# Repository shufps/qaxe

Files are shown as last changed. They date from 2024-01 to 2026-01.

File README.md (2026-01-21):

# NerdQ Hardware Repository

This repository contains multiple generations of small-scale Bitcoin miner hardware designs.

## NerdQAxe++



Current high-performance design based on 4× BM1370 ASICs.



- ~4.8 TH/s at ~76 W (~15.8 J/TH)
- Previous stable version (that was used for most NQ++): [rev5.1](https://github.com/shufps/qaxe/releases/tag/rev5.1)
- Latest:  [rev5.1.2](https://github.com/shufps/qaxe/releases/tag/rev5.1.2)*

*: contains some [improvements](https://github.com/shufps/qaxe/pull/31) but is untested yet.

## NerdQAxe+



Design based on 4x BM1368 ASICs.

- ~2.5TH/s at ~55 W (~22 J/TH)
- Latest revision 5.0

## Firmware for NQ+ and NQ++

The latest version can be found here:

https://github.com/shufps/ESP-Miner-NerdQAxePlus

## Legacy Designs

The following designs are **end of life** and no longer supported:

- QAxe+
- QAxe

They are provided for reference, documentation, and historical reasons only.

**No support, fixes, or updates will be provided for legacy designs.**

See `legacy/README.md` for full documentation of deprecated hardware.

---

## Compatible Replacement Parts

### For NerdQAxe++
- 25 MHz Oscillator
  Original: IQD LFSPXO076024
  Replacement: Taitien OXLTDLJANF-25.000000

### For NerdQAxe++ and NerdQAxe+
- 0.8 V LDO
  Original: Microchip MCP1824T-0802E-OT
  Replacement: TI TPS78408QDBVRQ1

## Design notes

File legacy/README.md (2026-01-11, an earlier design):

# Legacy Hardware Designs

⚠️ **Status: End of Support**

This directory contains deprecated hardware designs that are no longer maintained.

- No bug fixes
- No hardware revisions
- No firmware updates
- No user support

The designs are provided **as-is** for reference and historical documentation.

---

## QAxe+



Quad-BM1368 miner.

- ~2.4 TH/s at ~55 W (230 V measured)
- Final revisions: rev4 / rev4.1
- Known quirks with ASIC reset behavior

---

## QAxe



Quad-BM1366 miner.

- ~1.7–1.8 TH/s depending on revision
- Multiple early hardware revisions (rev1–rev3.2)

Notes:
- Boards with BOOT button require STM32L072CB
- USB DFU bootloader recommended for flashing

---

Firmware & Tooling
=====================

Legacy firmware, build instructions, and tooling are preserved for completeness.
They may require outdated dependencies and are not guaranteed to work on modern systems.

## Compilation (Bootloader or CMSIS-DAP) (QAxe, QAxe+)

### Dockered compilation and flashing
There is a wonderfull Docker based single-script compilation and flash tool for the QAxe Firmware:

https://github.com/AnimaI/QAxe-Docker-Bootloader

### Manual compilation and installation

```bash
# install curl
sudo apt install curl

# install rust
curl --proto '=https' --tlsv1.2 https://sh.rustup.rs -sSf | sh

# add to ~/.bash.rc (afterwards, opening a new terminal is needed)
echo 'source "$HOME/.cargo/env"' >> ~/.bashrc

# clone repository
git clone https://github.com/shufps/qaxe

# clone submodules
cd qaxe
git submodule init
git submodule update

# add rust target for STM32L0 variants
rustup target add thumbv6m-none-eabi

# or add rust target for STM32L1 variants
#rustup target add thumbv7m-none-eabi

# build firmware for L072
cd firmware/fw-L072CB
./build.sh
```

### Installation via USB Bootloader on board with `BOOT` button (QAxe, QAxe+)
The STM32L072CB variant has an integrated DFU Bootloader that starts when pressing the `BOOT` button during reset.

Afterwards the firmware can be flashed via `dfu-utils`:

```bash
# install cargo-binutils and llvm tools
cargo install cargo-binutils
rustup component add llvm-tools-preview

# create the firmware.bin
DEFMT_LOG=info cargo objcopy --release --bin qaxe -- -O binary qaxe.bin

# install dfu-utils
sudo apt-get install dfu-util

now start the stm32 in DFU mode by pressing `boot` (only works with the STM32L072CB variant)

# after booting, list the devices
dfu-util --list

# flash the binary
dfu-util -a 0 -s 0x08000000:leave -D qaxe.bin
```

Mining Client (QAxe, QAxe+)
=============



Stratum Mining Client:<br>
https://github.com/shufps/piaxe-miner

---

## Disclaimer

These designs are **not recommended for new builds**.

If you are looking for a supported and actively developed project, refer to the main repository README.

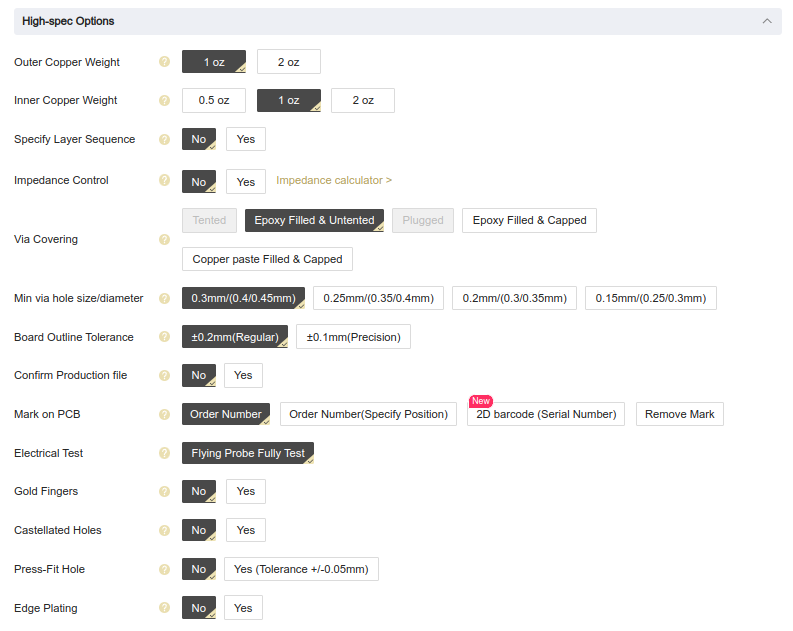
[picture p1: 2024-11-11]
nerdqaxe++/gerbers/jlc-settings2.png

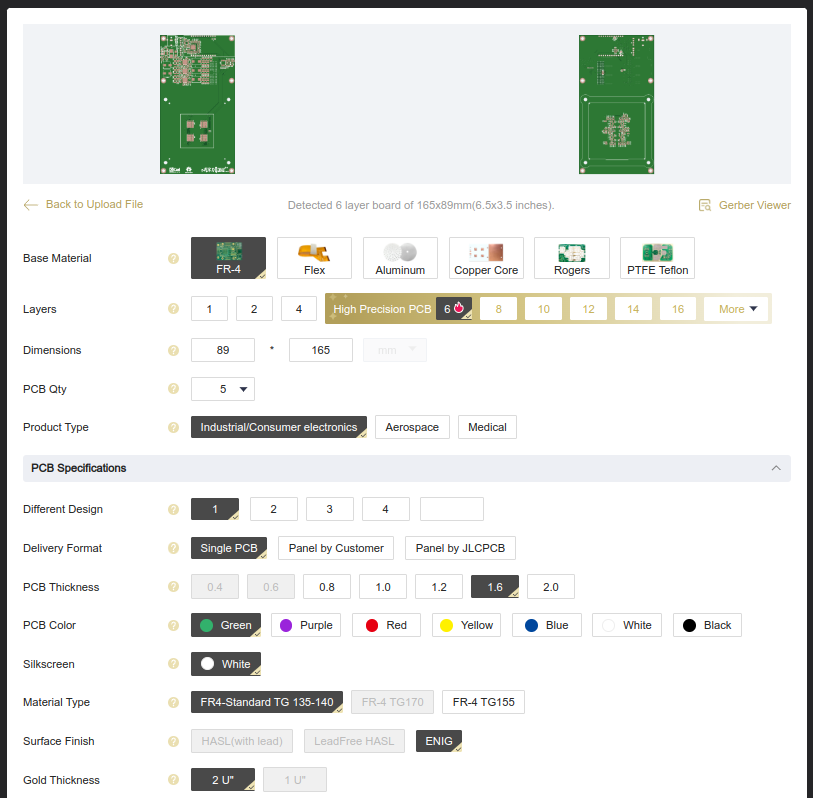
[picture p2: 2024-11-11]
nerdqaxe++/gerbers/jlc-settings1.png

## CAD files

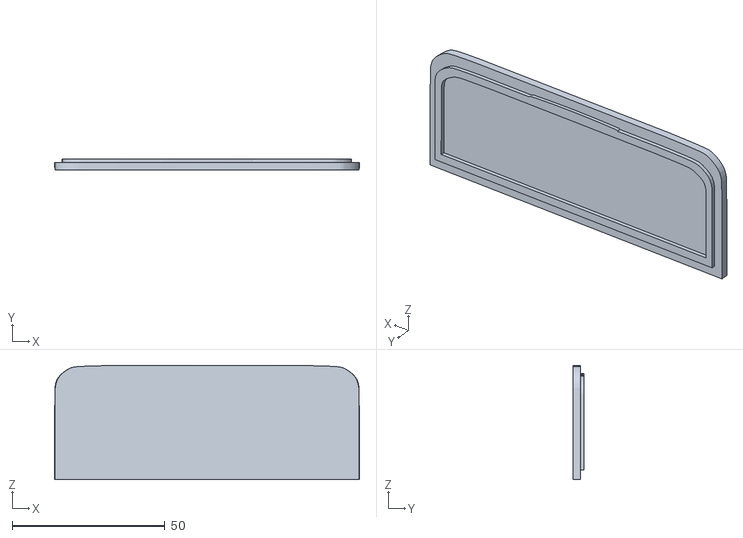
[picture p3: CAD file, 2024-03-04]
case/back.stl
99.7 x 3.54 x 37.3

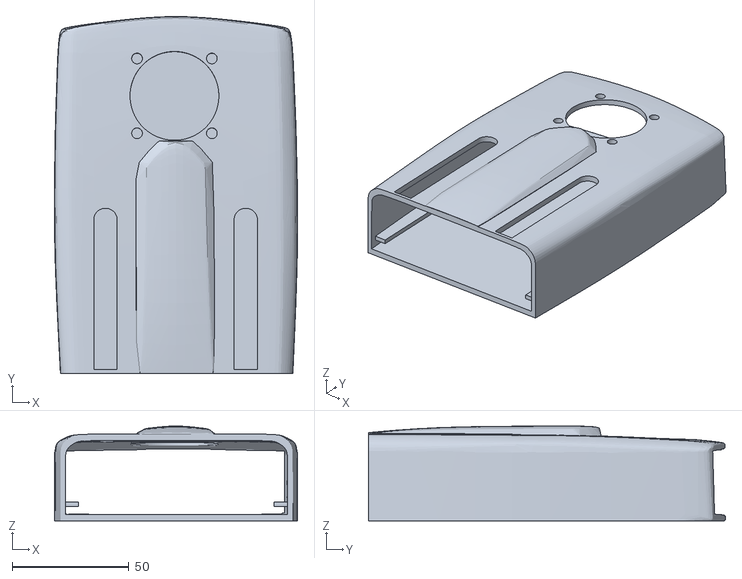
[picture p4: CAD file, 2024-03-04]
case/case.stl
104.1 x 152.7 x 40.6

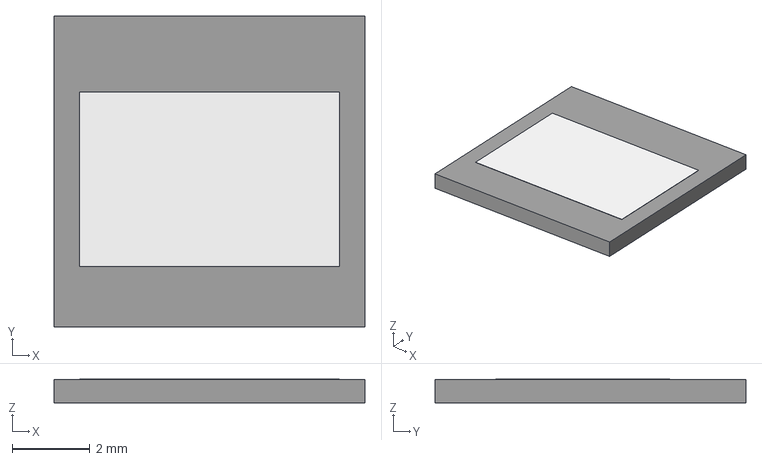
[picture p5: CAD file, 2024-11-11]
nerdqaxe++/nerdqaxe++/3d/bm1370.step
8.00 x 8.00 x 0.61 mm

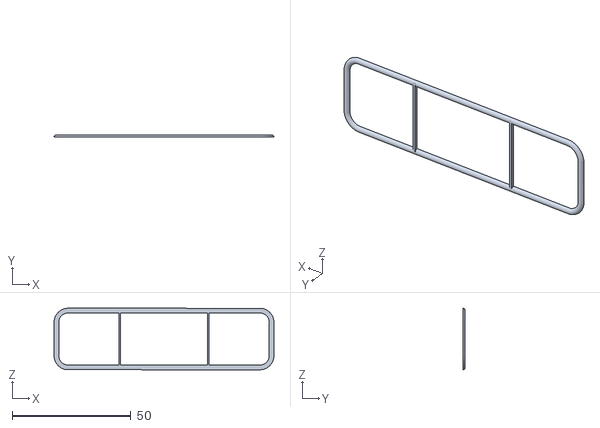
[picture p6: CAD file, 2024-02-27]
case/grill-part2.stl
92.7 x 1.00 x 26.0

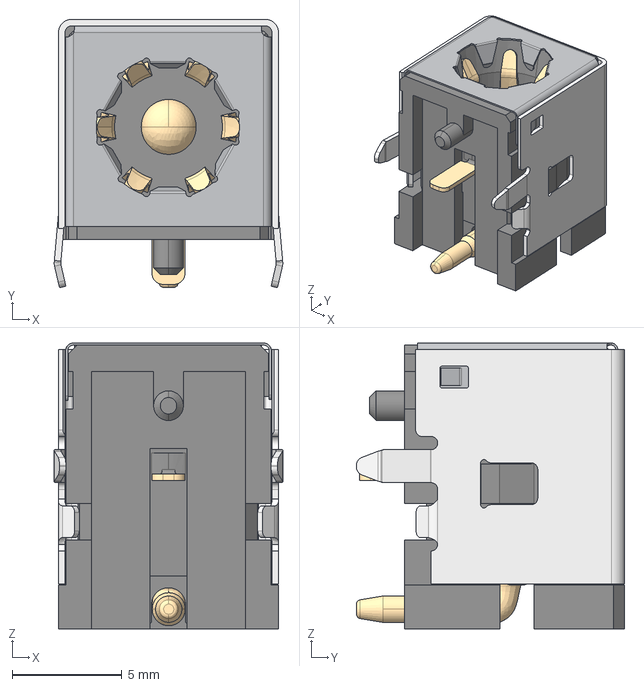
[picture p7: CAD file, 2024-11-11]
nerdqaxe++/nerdqaxe++/3d/DCJ250-20-B-XX-X_REVA1.step
10.4 x 12.2 x 13.0 mm

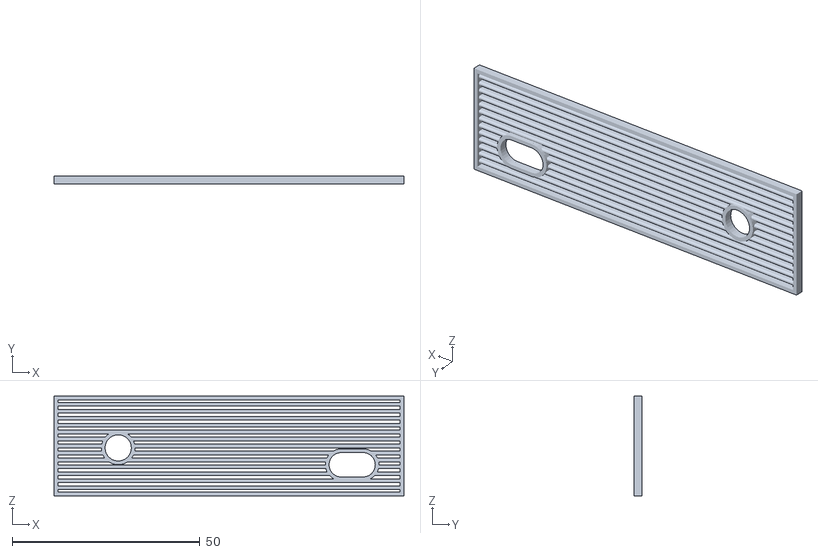
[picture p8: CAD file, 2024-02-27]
case/grill-part1.stl
93.2 x 2.00 x 26.5

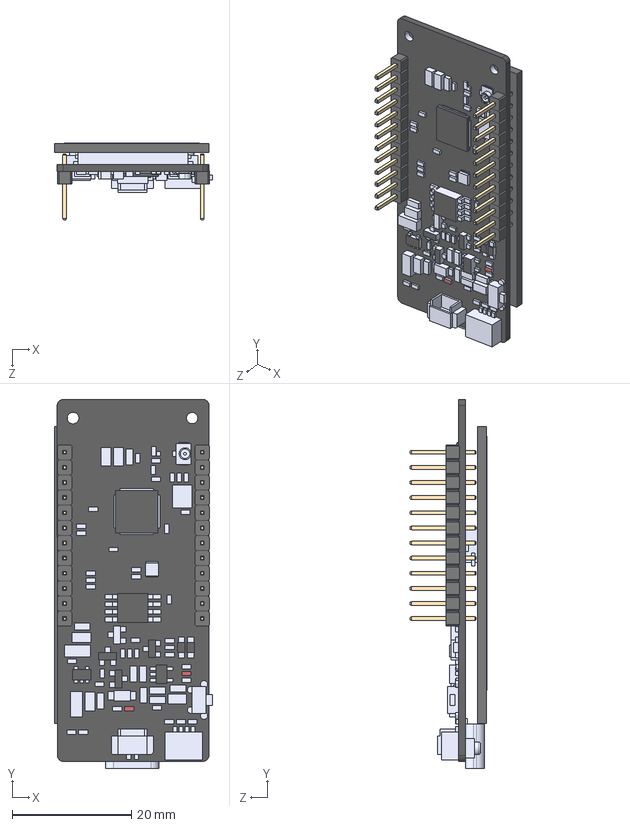
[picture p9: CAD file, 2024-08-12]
nerdqaxe++/nerdqaxe++/3d/T-Display-S3.STEP
26.5 x 62.0 x 12.9 mm
MainBoard_3D
Ecran
1_Male_Pin_2.54_mm x 24

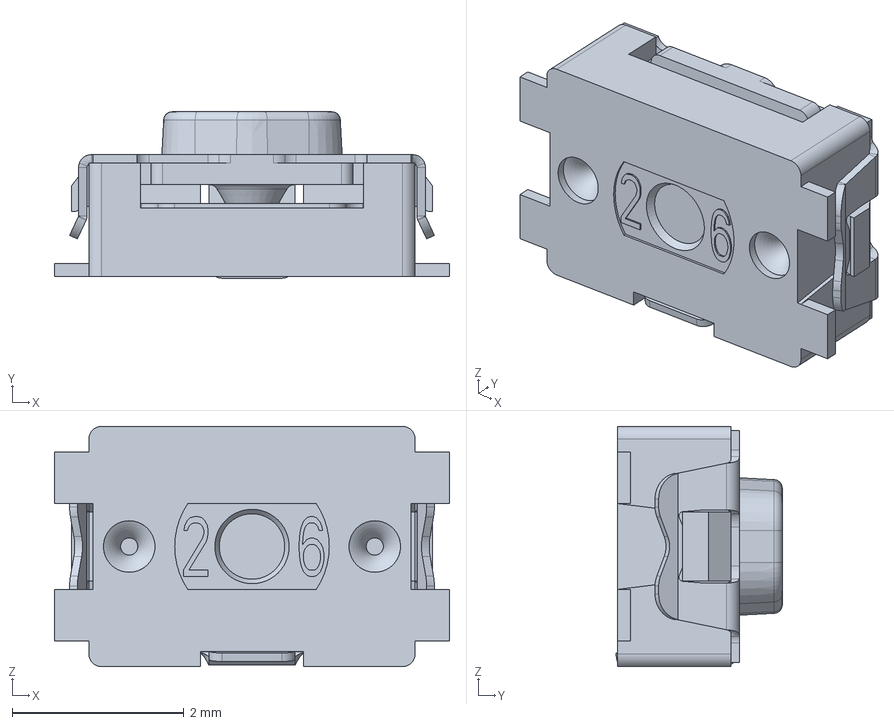
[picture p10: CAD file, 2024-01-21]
nerdqaxe++/nerdqaxe++/3d/KMR231GLFS.stp
4.60 x 1.94 x 2.80 mm

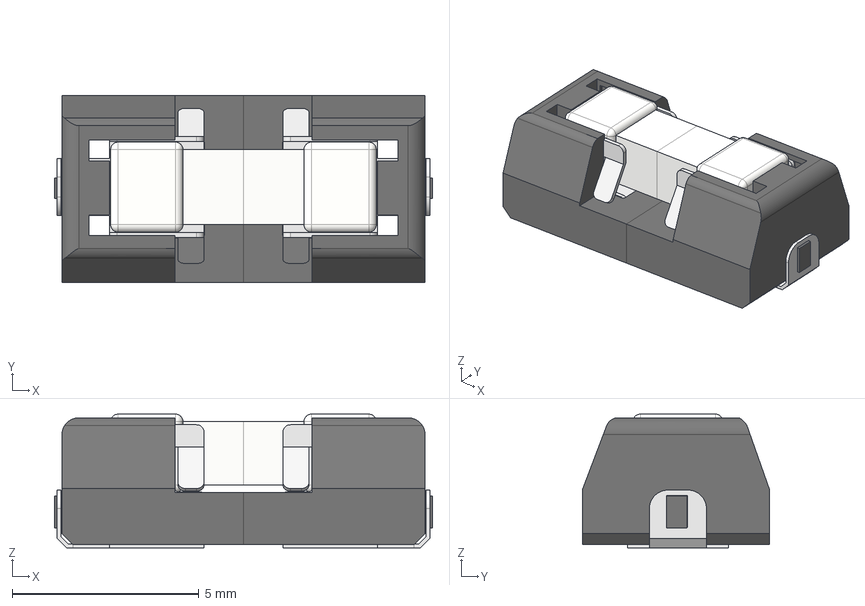
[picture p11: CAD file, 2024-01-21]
nerdqaxe++/nerdqaxe++/3d/Littelfuse 0154.500DRT without value_black v2.step
10.1 x 5.00 x 3.59 mm
Komponente1
Komponente2
Komponente3
Komponente4

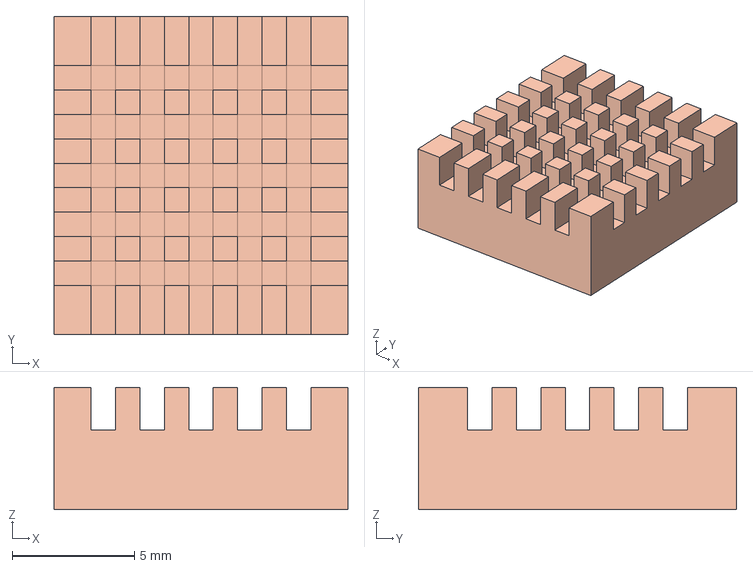
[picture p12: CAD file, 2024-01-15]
nerdqaxe++/nerdqaxe++/3d/heatsink-13x12x5.step
12.0 x 13.0 x 5.00 mm

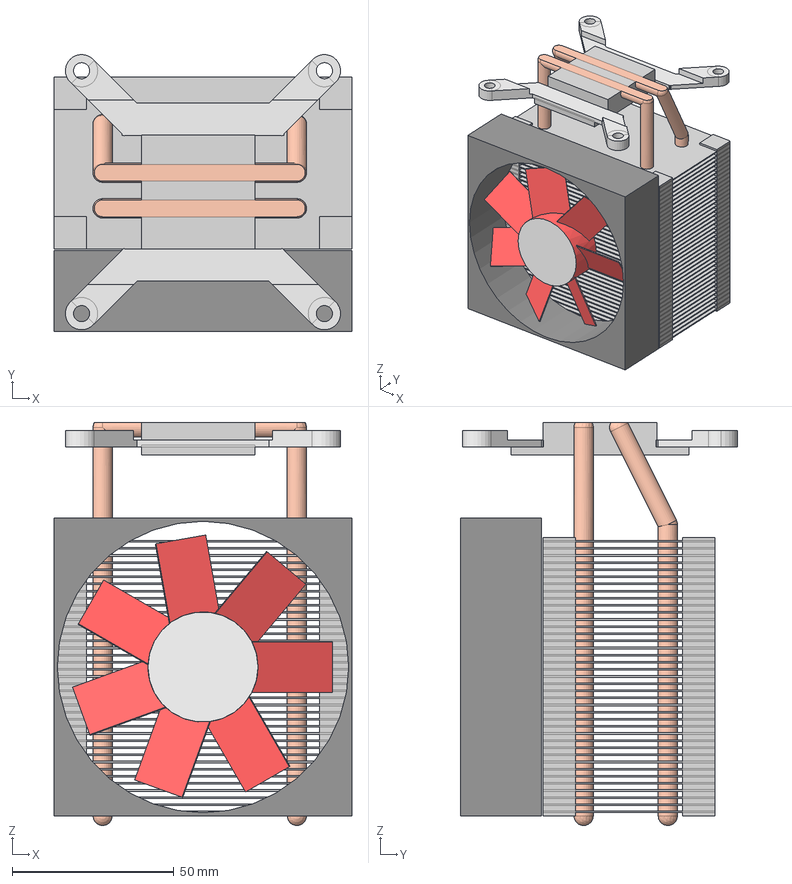
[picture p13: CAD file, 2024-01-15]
nerdqaxe++/nerdqaxe++/3d/lga115x.step
92.0 x 85.5 x 124.5 mm

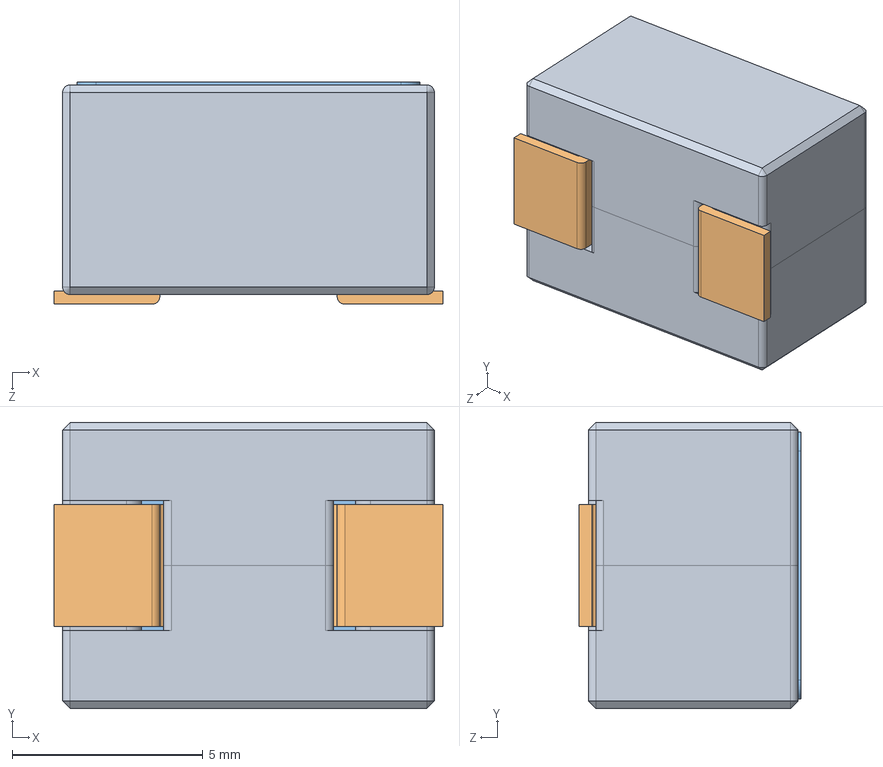
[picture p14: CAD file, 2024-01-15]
nerdqaxe++/nerdqaxe++/3d/FP1006V2-R.STEP
10.2 x 7.50 x 5.83 mm
11150900A x 2
53134900A
Label for FP1006V2-R

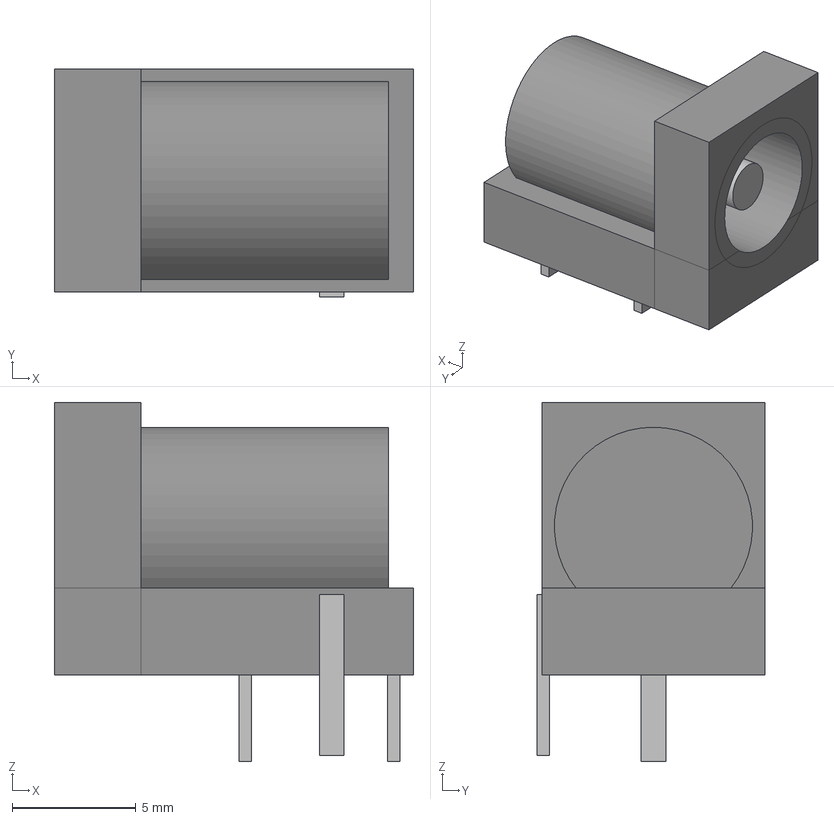
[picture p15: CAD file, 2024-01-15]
nerdqaxe++/nerdqaxe++/3d/barrel-jack.step
14.5 x 9.20 x 14.5 mm

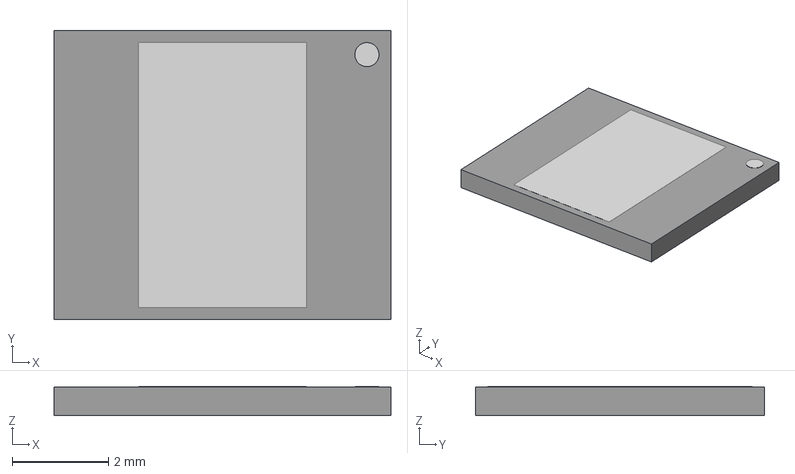
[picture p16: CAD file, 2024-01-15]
nerdqaxe++/nerdqaxe++/3d/bm1366.step
7.00 x 6.00 x 0.61 mm

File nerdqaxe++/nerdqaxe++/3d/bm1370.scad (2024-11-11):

$fn=50;

color("#505050") translate([0,0,0.3]) cube([8,8,0.6], center=true);
color("lightgray") translate([0,-0.2,0.51]) cube([6.7, 4.5, 0.2], center=true);

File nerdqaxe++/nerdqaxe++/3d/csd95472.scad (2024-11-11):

$fn=50;

color("#505050") translate([0,0,0.5]) cube([5,6,1], center=true);

color("lightgray") union() {
    for (i=[-5:5]) {
        translate([5/2-0.24, i*0.5, 0.095]) cube([0.5, 0.25, 0.2], center=true);
        translate([-5/2+0.24, i*0.5, 0.095]) cube([0.5, 0.25, 0.2], center=true);
    }
    
    translate([1+0.25/2, 3-0.10, 0.1]) cube([0.25, 0.3, 0.25], center=true);
    translate([-(1+0.25/2), 3-0.10, 0.1]) cube([0.25, 0.3, 0.25], center=true);

    translate([1+0.25/2, -(3-0.10), 0.1]) cube([0.25, 0.3, 0.25], center=true);
    translate([-(1+0.25/2), -(3-0.10), 0.1]) cube([0.25, 0.3, 0.25], center=true);

    translate([0, 0, 0.1]) cube([3, 5.5, 0.25], center=true);    
}

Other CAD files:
nerdqaxe++/nerdqaxe++/3d/csg95472.step

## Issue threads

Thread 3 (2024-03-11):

Add 5V power to USB port (for Pi Zero)

AxisRay, 2024-03-11:
Can you add 5V power to USB port?
So I can connect the Pi Zero with just one cable.
And it does not require an additional power adapter.
The Pi Zero consumes less than 600mA of power.
Perhaps that 5V buck circuit can handle the load.

shufps, 2024-03-29:
Interesting idea :thinking:  Mmhmmmm, it could work :thinking: would be cool if the existing usb-c could be used for powering the Pi but I don't think it works this way :see_no_evil:

AxisRay, 2024-04-19:
I think it will work.
I have used a OTG cable with power supply.
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

bohnelang, 2024-06-16:
It would be nice too if you could add 2 pin holes with 12V and GND next to the power socket. In the front part of the board you have already 4 holes for mounting. With some spacer one could design a carrier board that can take a NanoPi NEO v1.4 (Allwinner H3) or a Pi Zero or a ZeroPi (this is not a Pi Zero). Like a sandwich. To supply any future carrier board with power this small modification would be nice. The carrier board itself can use a down stepper (12V to 5V) to supply the Pi or other micro controllers .

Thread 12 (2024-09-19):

Update digikey.csv / ibom.html

marplukiwi, 2024-09-19:
I compared all the articles for the NerdQAxe+ from the digikey.csv with the ibom.html and I noticed the following discrepancies that need to be clarified.

Capacitors

C15, C17, C21, C22, C24, C39 are supposed to have 100µF 6.3V but in the digikey.csv the article 399-C1210C107M8PAC7800CT-ND has 100µF 10V. Can this also be used?

C112, C117 are supposed to have 3.3n/25V. The article 490-8291-1-ND from the digikey.csv has 3.3n/100V

The capacitor C100 with 10µ/25V is not included in the .csv. Was this forgotten or is the capacitor not needed according to the latest version?

Then I noticed that in the PCB editor the labeling of the capacitors C90 and C21 is swapped compared to the Ibom. Is that a mistake?

Do the solder jumpers JP1, JP, and JP3 have to be installed? In the circuit diagram they are drawn as open.

I just want the documentation to be clean so that it is easier for others.

MyOwn2C, 2025-03-03:
One more change for NerdQAxe+ is to replace the 5A fuse with 8A fuse:

8A Fuse:
https://www.digikey.ca/short/2pwrfv2t

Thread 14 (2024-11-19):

NerdQAxe++ build guide

invisibleecho, 2024-11-19:
Hello,

I was about to order an avalon nano 3, but 4TH/s @ 140Watts is not too efficient. I saw bitaxe gamma at 1.2TH/s @ 15Watts which is impressive but expensive for like 229€ each unit.

Im aiming to get an efficient home miner which gets good speed like 8TH/s under 200 Watts and your project looks insane!

Are there any tutorials on how to build this yourself? Do you have a list of parts and where to get the correct parts or something like this?

I need one of those! :)

Thanks for your awesome work!

Best regards

shufps, 2024-12-06:
Hi,

thank you a lot for your interest in this project :hugs:

> Are there any tutorials on how to build this yourself? Do you have a list of parts and where to get the correct parts or something like this?

Hmm, to be honest, the complexity of such miner is on "pro-level" and even people with skills obtained over decades struggle with it.

So I guess there is no tutorial how to do it - if you have the skills required the information from this repository are enough (the project has been completed by several people already - with maybe a little help in the OSMU Discord channel). :speak_no_evil:

Yes, there is a list of parts called BOM (bill of material). This are csv lists that can be imported into Digikey for ordering.

Best regards

Closed 2024-12-06.

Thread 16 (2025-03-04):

Change power connector as an improvement

Comphil, 2025-03-04:
I was wondering whether it is possible to replace the power connector on the nerdqaxe++ (BOM: J1). The connector is difficult to order and I don't find any alternatives. It's possible to change to an XT30U-M in vertical position? I think you have no problems with the amperage [A] and the voltage [V]. I'm aware that it requieres a special cable, wich I can make myself (together with a meanwell power supply).
Can someone adapt the pcb-board for me (unfortunately I have only a little experience with kicad).
Maybe this suggestion should be seen as an improvement and incorporated into the project?
Thank you and stay healthly.

shufps, 2025-03-05:
👋 Hmm I had a look at it and I haven't found any nice way to use optionally a XT30 connector because I want to keep the barrel jack because most people use it.

Maybe you can solder cables directly to the board instead of using the barrel jack connector?

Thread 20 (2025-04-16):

Bug Report: Unexpected Fan Stoppage During Power-On with Single 1370 Chip Testing

myeyesareopen, 2025-04-16:
Description
When testing the 1370 chip using NerdQAxe, I consistently observe unexpected fan behavior during system startup:

Observed Symptoms :

Case 1:
Fan spins up after power-on
Then decelerates/stops unexpectedly
Subsequently accelerates again and boots normally
Case 2:
Fan spins for 3-5 seconds after power-on
Completely stops with boot failure
Additional Context :

Issue persists across multiple firmware versions from 1.0.25 to 1.0.28.1

Request :
Could you help confirm:
Is this a known/common issue with the 1370 chip?
Any recommended configuration adjustments?
Required debug data for further analysis?

shufps, 2025-06-18:
Mmhmm, can be that this is the "fan polarity auto detection" feature that tries two different fan settings to find out which PWM polarity is the correct one.

It hmm stops with boot failure? How does this look like?

Have you photos or a log you could post?

PS: The auto detect feature can be turned off in the "Danger Zone".

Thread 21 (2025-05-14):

Feature Request: Support ASIC Temperature Readout for BM1370 (Display, Logs, API)

IxTechCrypto, 2025-05-14:
**Request**
Requesting support to read the ASIC temperature directly from the BM1370 chip—similar to how Bitaxe and NerdAxe Gamma implementations handle temperature monitoring (Skot and Bitmaker may have more insight on how to implement this). This would enhance observability and thermal safety, especially for users running overclocked configurations.

**Expected Behavior**
Temperature is read from internal BM1370 registers

**Output is:**
- Logged via UART/serial
- Avg chip temp displayed on Lillygo screen
- Exposed through any available web API or telemetry endpoints

IxTechCrypto, 2025-05-21:
moving to the esp miner repo

Closed 2025-05-21.

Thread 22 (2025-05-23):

TPS_TSEN network is a single-point network

manan1199, 2025-05-23:
Should pin 40 of U3 be connected to pin 11 of U4, U9, and U10? Their network names seem to be the same, but they are all single-point networks. The specification sheet indicates that connecting them would be more beneficial for detecting the temperature of the power system.

Closed 2025-06-01.

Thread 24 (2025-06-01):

Wrong Pinout for II2C and UART

FireCloudHD, 2025-06-01:
The pinout for the II2C and UART interface (Signal names: TXD, RXD, SDA, SCL) do not match the pinout of the T-Display-S3 from this repository: https://github.com/Xinyuan-LilyGO/T-Display-S3

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

Is this an error in the schematic, or is the pinout intended for a different T-Display-S3?

Happy to hear any suggestions, thank you.

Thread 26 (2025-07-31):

Feature request: Log PCB reference next to ASIC number

janix12, 2025-07-31:
Hi,

I'd like to request a small improvement in the log output.
Currently, ASICs are identified in the logs as:

AsicNr 0
AsicNr 1
AsicNr 2
AsicNr 3
It would be very helpful if the corresponding PCB / KiCad reference (e.g., U20, U19, etc.) could also be printed alongside, like this:

AsicNr 0 - U20
AsicNr 1 - U19
...
This would make it much easier to locate and repair faulty ASICs during debugging or hardware servicing.
Thanks in advance for considering this!

Best regards,
János

Closed 2025-07-31.

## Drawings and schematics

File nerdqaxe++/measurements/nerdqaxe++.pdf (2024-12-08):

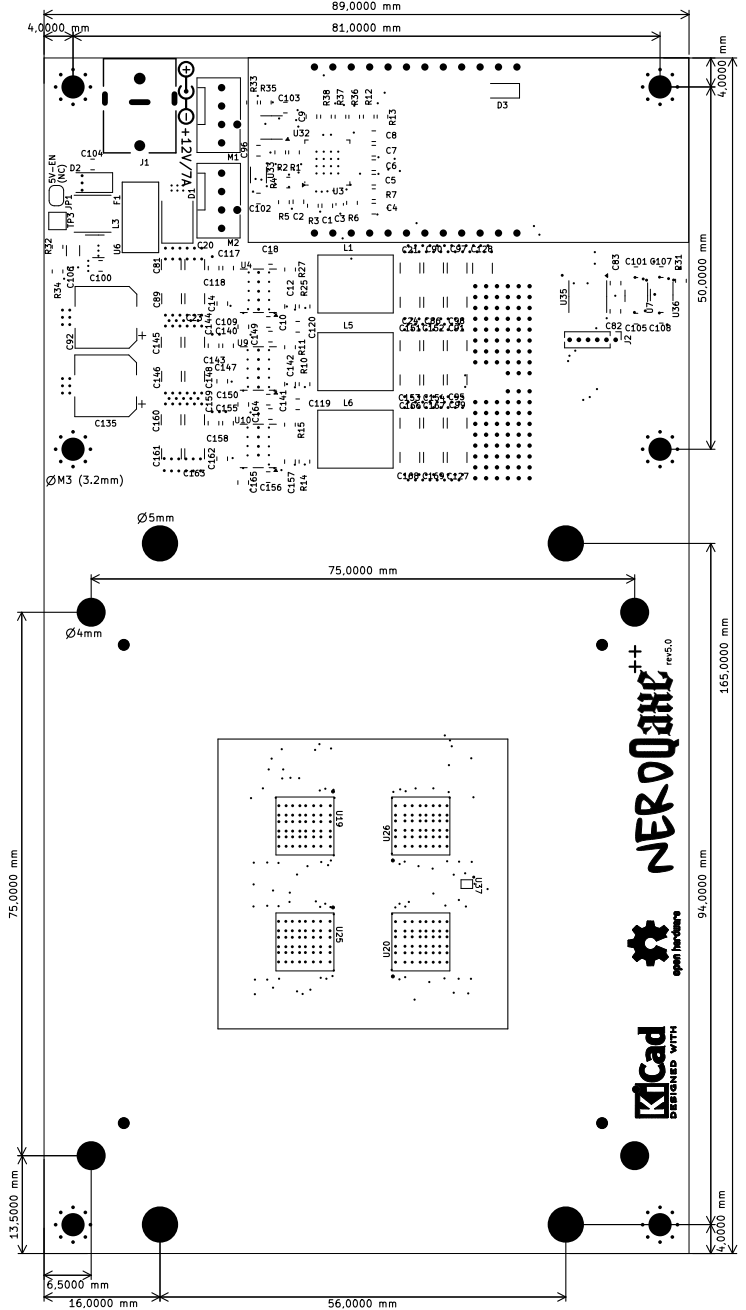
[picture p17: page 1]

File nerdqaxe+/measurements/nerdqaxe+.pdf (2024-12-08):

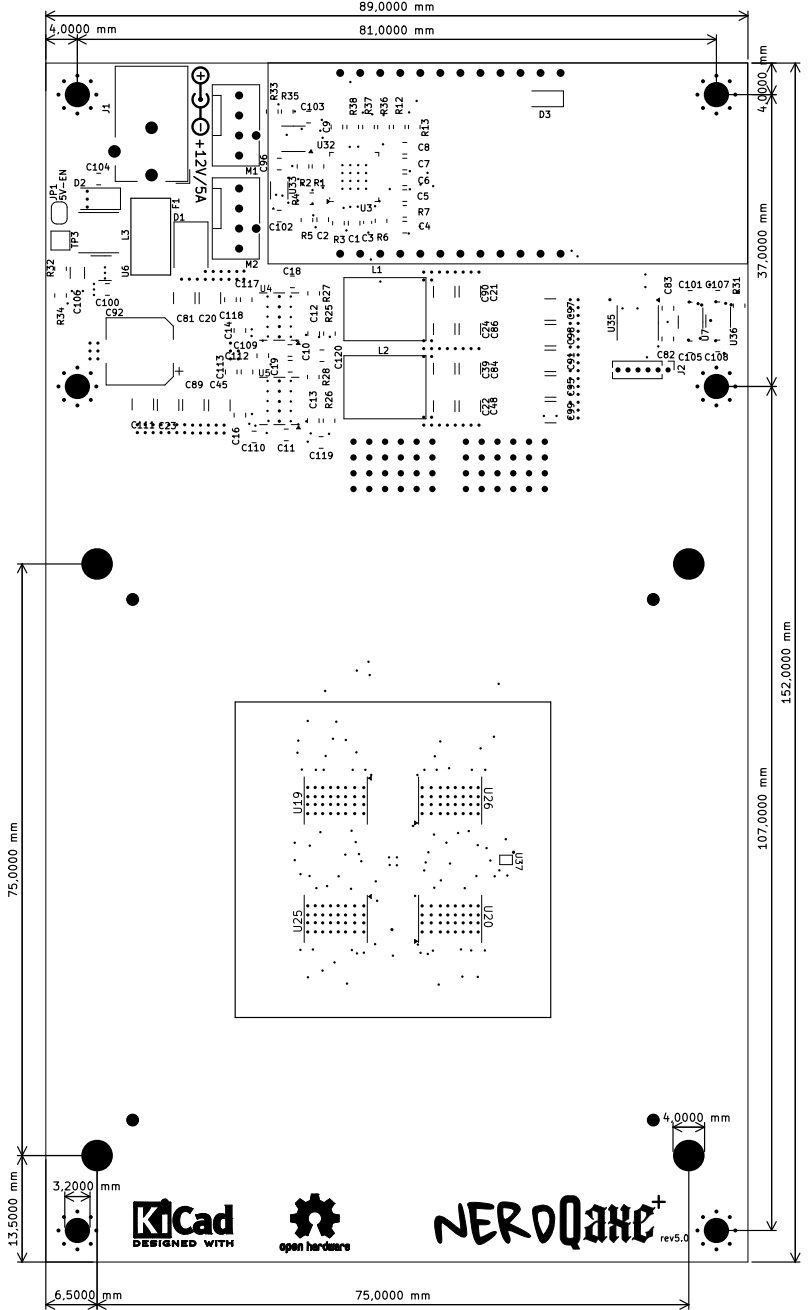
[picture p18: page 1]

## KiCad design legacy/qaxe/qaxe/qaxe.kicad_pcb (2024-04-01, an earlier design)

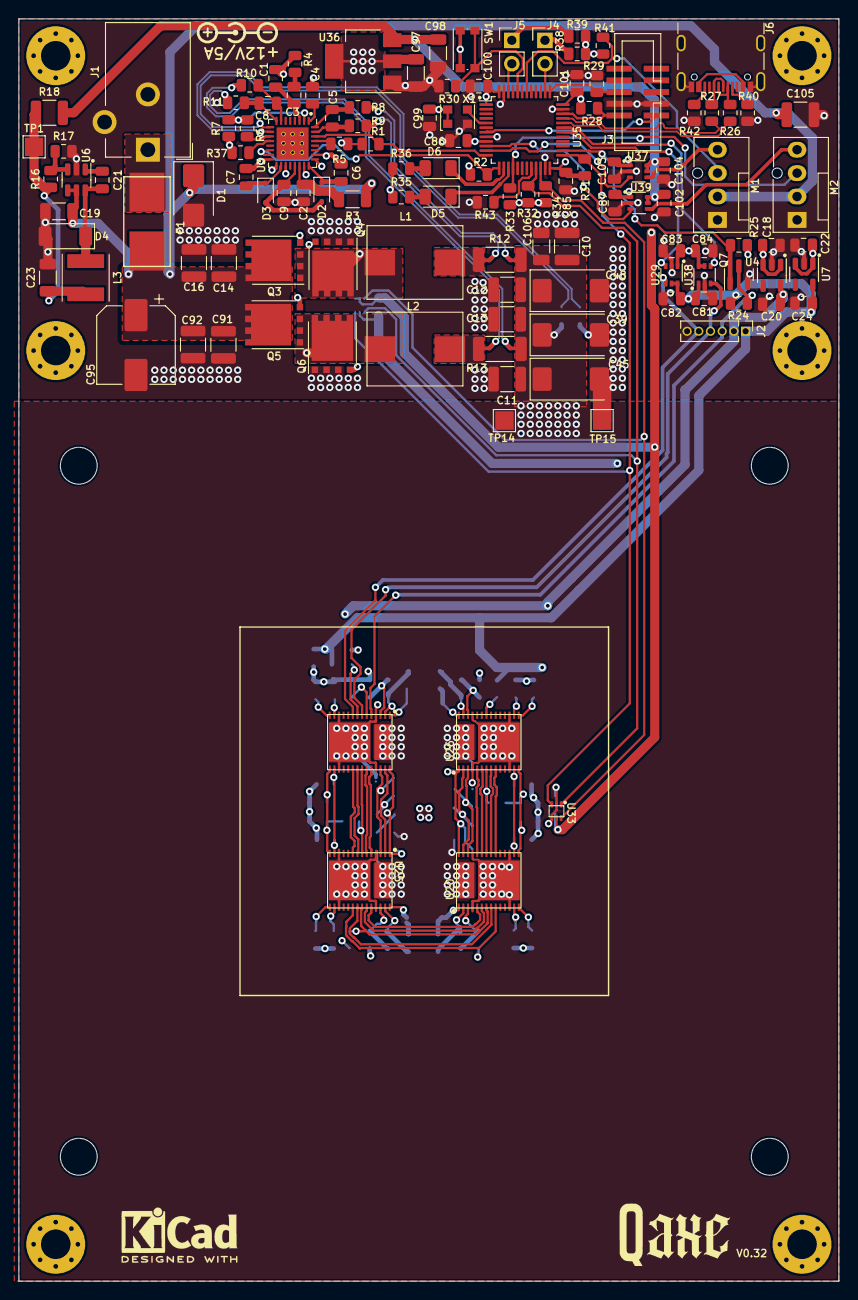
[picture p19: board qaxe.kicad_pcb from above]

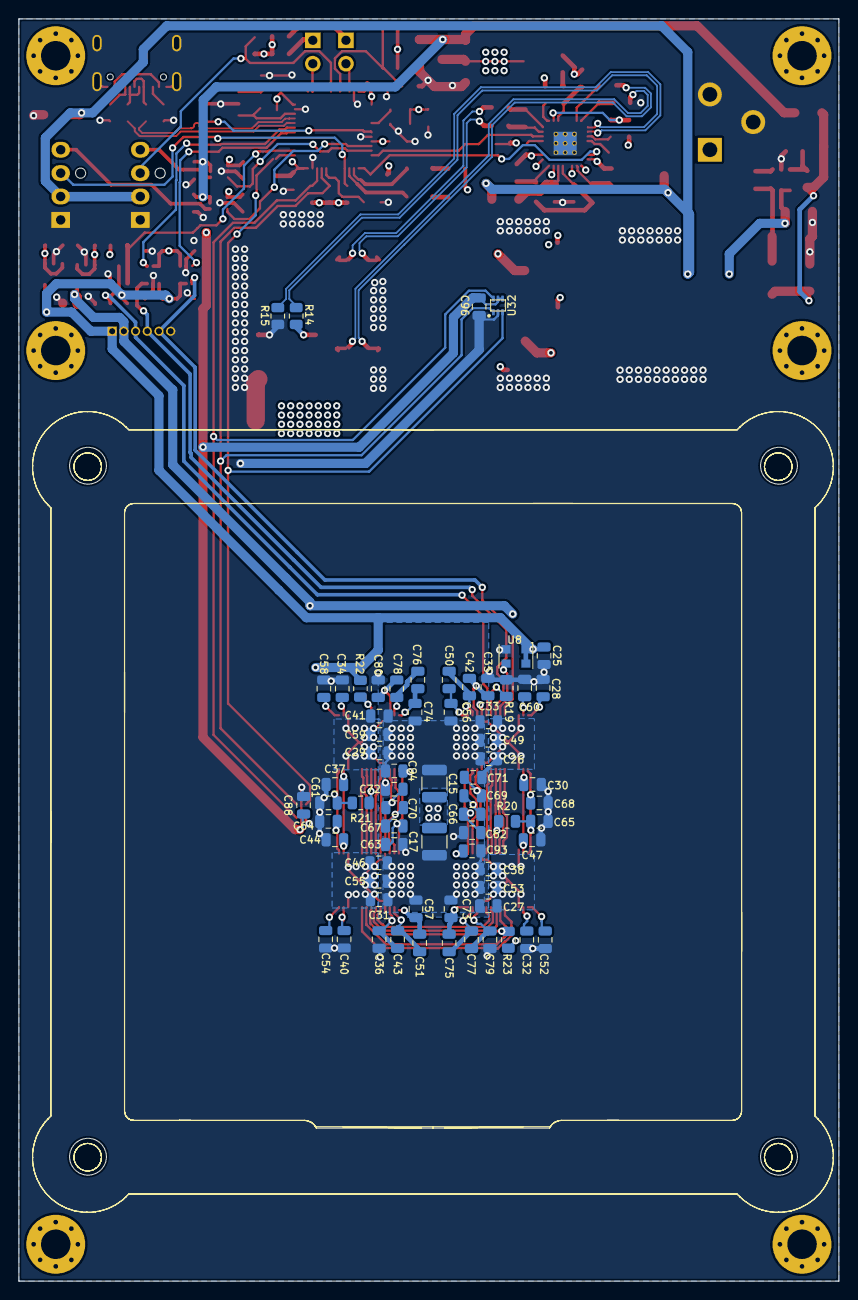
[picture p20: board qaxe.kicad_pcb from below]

Board: 4 copper layers, 89.0 x 137.0 mm, 198 parts (68 on the bottom side), 115 nets.

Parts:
C1: 47p; C_0805_2012Metric
C2, C4, C6, C7, C18, C22, C25, C49, C53, C55, C59, C81, C82, C83, C84, C85, C86, C87, C88, C96, C99, C100, C101, C102, C103, C104: 100n; C_0805_2012Metric
C3: 3.3n; C_0805_2012Metric
C5, C8: 1n; C_0805_2012Metric
C9: 4.7µ/25V; C_0805_2012Metric
C10, C11, C12, C13, C15, C17: 100µ/6.3V; C_1210_3225Metric
C14, C16, C91, C92, C105: 22µ/25V; C_1210_3225Metric
C19, C98: 10µF/50V; C_1206_3216Metric
C20, C24, C28, C30, C32, C33, C34, C35, C36, C37, C38, C40, C41, C42, C43, C44, C46, C47, C50, C51, C52, C54, C56, C57, C58, C60, C61, C62, C63, C64, C65, C66, C67, C68, C69, C70, C71, C72, C73, C74, C75, C76, C77, C78, C79, C80, C93, C94: 1µ; C_0805_2012Metric
C21: 10n/250V; C_0805_2012Metric
C23, C97: 22µ/16V; C_1206_3216Metric
C26, C27, C29, C31: 10µ/16V; C_0805_2012Metric
C39, C45, C48: 330µ/6.3V; CP_EIA-7343-15_Kemet-W
C95: 220µ/25V; CP_Elec_8x10
C106: 4.7µ/6.3V; C_1206_3216Metric
D1: SMBJ12A; D_SMB
D2, D3: CMDSH-3; D_SOD-323
D4: PMEG4030EP,115; D_SOD-128
D5, D6: LED; LED_1206_3216Metric
F1: 5A; fuseholder_littlefuse_blok
J1: Barrel_Jack_Switch; BarrelJack_CUI_PJ-102AH_Horizontal
J2: Conn_01x06; PinHeader_1x06_P1.27mm_Vertical
J3: SWD; PinHeader_IDC_2x05_P1.27mm_Vertical_SMD
J4, J5: Conn_01x02; PinHeader_1x02_P2.54mm_Vertical
J6: USB_C_Receptacle_USB2.0; USB_C_Receptacle_GCT_USB4105-xx-A_16P_TopMnt_Horizontal
L1, L2: 220nH; IFLR-4031GC-01-8x10
L3: 4.7µH/2A/3A; L_Taiyo-Yuden_NR-50xx
M1, M2: Fan_4pin; FanPinHeader_1x04_P2.54mm_Vertical
NT1, NT2, NT3, NT4: NetTie_2; NetTie-2_SMD_Pad0.5mm
NT7: NetTie_2; NetTie-2_L3_SMD_Pad0.5mm
Q3, Q4, Q5, Q6: CSD16415Q5T; VSONP-8-1EP_5x6_P1.27mm
Q7: BSS138; SOT-23
R1, R19, R20, R21, R22, R23, R24, R25, R28, R29, R31, R43: 10k; R_0805_2012Metric
R2, R32, R34: 1.5k; R_0805_2012Metric
R3: 2.2R; R_1206_3216Metric
R4: 8.45k; R_0805_2012Metric
R5, R30: 100k; R_0805_2012Metric
R6: 22k; R_0805_2012Metric
R7: 20k; R_0805_2012Metric
R8, R9, R10, R11: 200; R_0805_2012Metric
R12, R13: 1mR; R_2010_5025Metric
R14, R15: 10; R_0805_2012Metric
R16: 84.5k; R_0805_2012Metric
R17: 16.3k; R_0805_2012Metric
R18: 0; R_1210_3225Metric
R26, R27: 22; R_0805_2012Metric
R33, R41: 2.7k; R_0805_2012Metric
R35, R36, R38, R39: 560; R_0805_2012Metric
R37: 49.9k; R_0805_2012Metric
R40, R42: 5.1k; R_0805_2012Metric
SW1: boot; SW_Push_1P1T_NO_CK_KMR2
TP1, TP14, TP15: 3V3; TestPoint_Pad_2.0x2.0mm
U1: polarity
U3: LTC3856; QFN-32-1EP_5x5mm_P0.5mm_EP3.45x3.45mm_ThermalVias
U4: MCP1824T-0802E; SOT-23-5
U6: AP3211; SOT-23-6
U7: MCP1824T-1802E; SOT-23-5
U8: 25MHz; Oscillator_SMD_EuroQuartz_XO32-4Pin_3.2x2.5mm
U19, U20, U25, U26: BM1366_mode1; BM1366
U29, U37, U38, U39: TXU0101; SOT-363_SC-70-6
U32, U33: TMP1075; TMP1075-DRL
U35: STM32L072CBT6; LQFP-48_7x7mm_P0.5mm
U36: 1117-3.3; SOT-223-3_TabPin2
X1: 8MHz; Oscillator_SMD_EuroQuartz_XO32-4Pin_3.2x2.5mm

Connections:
+0V8: C20.1, C28.2, C30.2, C32.2, C34.2, C37.2, C40.2, C44.2, C47.2, J2.2, U4.5 (VOUT), U19.13 (VDDIO_08_0), U19.16 (VDDIO_08_1), U20.13 (VDDIO_08_0), U20.16 (VDDIO_08_1), U25.13 (VDDIO_08_0), U25.16 (VDDIO_08_1), U26.13 (VDDIO_08_0), U26.16 (VDDIO_08_1)
+1V2: C10.1, C11.1, C12.1, C13.1, C15.1, C17.1, C26.1, C27.1, C29.1, C31.1, C33.1, C38.1, C39.1, C41.1, C45.1, C46.1, C48.1, C49.1, C53.1, C55.1, C56.2, C57.2, C59.1, C62.1, C63.1, C73.1, C74.1, C93.2, C94.2, C106.1, NT3.1, NT4.2, R12.2, R13.2, R14.1, TP14.1, U19.29 (VDD), U20.29 (VDD), U25.29 (VDD), U26.29 (VDD)
+1V8: C24.1, C25.1, C52.1, C54.1, C58.1, C60.1, C61.1, C64.1, C65.1, C68.1, C81.1, C82.1, J2.1, R20.2, R21.2, R22.2, R23.2, R24.2, U7.5 (VOUT), U8.1 (Standby), U8.4 (VDD), U19.14 (VDDIO_18_0), U19.15 (VDDIO_18_1), U20.14 (VDDIO_18_0), U20.15 (VDDIO_18_1), U25.14 (VDDIO_18_0), U25.15 (VDDIO_18_1), U26.14 (VDDIO_18_0), U26.15 (VDDIO_18_1), U29.5 (OE), U29.6 (VCCB), U38.1 (VCCA)
+3V3: C18.1, C22.1, C83.1, C84.1, C85.1, C86.1, C87.1, C88.1, C96.1, C97.1, C99.1, C100.1, C101.1, C103.1, R2.1, R25.2, R28.2, R31.1, R32.1, R33.1, R34.1, R35.1, R36.1, R38.1, R39.1, R41.1, SW1.2, U4.1 (VIN), U4.3 (EN), U7.1 (VIN), U7.3 (EN), U29.1 (VCCA), U32.4 (A0), U32.5 (V+), U33.5 (V+), U35.1 (VLCD), U35.9 (VDDA), U35.24 (VDD), U35.36 (VDD), U35.48 (VDD), U36.2 (VO), U37.1 (VCCA), U38.5 (OE), U38.6 (VCCB), U39.1 (VCCA), X1.1 (EN), X1.4 (V+)
+5V: C98.1, C102.1, C104.1, R18.2, U36.3 (VI), U37.5 (OE), U37.6 (VCCB), U39.5 (OE), U39.6 (VCCB)
+12V: C14.1, C16.1, C19.1, C91.1, C92.1, C95.1, C105.1, D1.1 (A1), F1.1, M1.2 (+), M2.2 (+), Q3.3 (D), Q5.3 (D), R3.1, U6.4 (EN), U6.5 (IN)
/BM1366/BI: R19.2, U19.6 (BI)
/BM1366/CI: J2.5, U19.9 (CI), U29.4 (BY)
/BM1366/CLKI: U8.3 (Out), U19.8 (CLKI)
/BM1366/RESET: Q7.1 (G), R25.1, U35.26 (PB13)
/BM1366/RO: J2.4, U19.7 (RO), U38.3 (A)
/BM1366/RST_N: J2.3, Q7.3 (D), R24.1, U19.5 (NRSTI)
/BM1366/RXD: U35.31 (PA10), U38.4 (BY)
/BM1366/TXD: U29.3 (A), U35.30 (PA9)
/Power/1V2_PGOOD: R2.2, U3.15 (PGOOD), U35.13 (PA3)
/Power/1V2_RUN: R1.2, U3.30 (RUN), U35.12 (PA2)
/Power/DIFF+: R14.2, U3.9 (DIFFP)
/Power/DIFF-: R15.2, U3.10 (DIFFN)
/Power/SENSE1+: NT1.2, R9.1
/Power/SENSE1-: NT3.2, R8.2
/Power/SENSE2+: NT2.1, R10.2
/Power/SENSE2-: NT4.1, R11.2
/STM32/ALERT2: R31.2, U32.3 (ALERT), U33.3 (ALERT), U35.25 (PB12)
/STM32/LED1: D6.1 (K), U35.14 (PA4)
/STM32/LED2: D5.1 (K), U35.15 (PA5)
/STM32/LED3: J4.2, U35.38 (PA15)
/STM32/LED4: J5.2, U35.46 (PB9)
/STM32/NRST: J3.1, U35.7 (NRST)
/STM32/PWM1: U35.10 (PA0), U39.3 (A)
/STM32/PWM2: U35.11 (PA1), U37.3 (A)
/STM32/SCL2: R32.2, U32.1 (SCL), U33.1 (SCL), U35.21 (PB10)
/STM32/SDA2: R34.2, U32.6 (SDA), U33.6 (SDA), U35.22 (PB11)
/STM32/SWCLK: J3.6, R29.2, U35.37 (PA14)
/STM32/SWDIO: J3.2, R28.1, U35.34 (PA13)
/STM32/TACHO1: M2.3 (Tacho), R33.2, U35.16 (PA6)
/STM32/TACHO2: M1.3 (Tacho), R41.2, U35.42 (PB6)
/STM32/USB_D+: R27.1, U35.33 (PA12)
/STM32/USB_D-: R26.1, U35.32 (PA11)
GND: C2.1, C9.2, C10.2, C11.2, C12.2, C13.2, C14.2, C15.2, C16.2, C17.2, C18.2, C19.2, C20.2, C22.2, C23.2, C24.2, C25.2, C26.2, C27.2, C28.1, C29.2, C30.1, C31.2, C32.1, C33.2, C34.1, C35.1, C36.1, C37.1, C38.2, C39.2, C40.1, C41.2, C44.1, C45.2, C46.2, C47.1, C48.2, C49.2, C52.2, C53.2, C54.2, C55.2, C58.2, C59.2, C60.2, C61.2, C64.2, C65.2, C68.2, C71.2, C72.2, C79.2, C80.2, C81.2, C82.2, C83.2, C84.2, C85.2, C86.2, C87.2, C88.2, C91.2, C92.2, C95.2, C96.2, C97.2, C98.2, C99.2, C100.2, C101.2, C102.2, C103.2, C104.2, C105.2, C106.2, D1.2 (A2), D4.2 (A), J1.2, J1.3, J2.6, J3.3, J3.4, J6.A1 (GND), J6.A12 (GND), J6.B1 (GND), J6.B12 (GND), J6.S1 (SHIELD), M1.1 (-), M2.1 (-), NT7.2, Q4.1 (S), Q6.1 (S), Q7.2 (S), R15.1, R17.2, R19.1, R29.1, R30.1, R40.1, R42.1, R43.1, TP15.1, U3.33 (SGND), U4.2 (GND), U6.2 (GND), U7.2 (GND), U8.2 (GND), U19.4 (VDD4_0), U19.12 (PLL_VSS), U19.17 (VSS), U19.25 (VDD4_0), U19.30 (GND), U20.4 (VDD4_0), U20.12 (PLL_VSS), U20.17 (VSS), U20.25 (VDD4_0), U20.30 (GND), U25.4 (VDD4_0), U25.12 (PLL_VSS), U25.17 (VSS), U25.25 (VDD4_0), U25.30 (GND), U26.4 (VDD4_0), U26.12 (PLL_VSS), U26.17 (VSS), U26.25 (VDD4_0), U26.30 (GND), U29.2 (GND), U32.2 (GND), U33.2 (GND), U33.4 (A0), U35.8 (VSSA), U35.23 (VSS), U35.35 (VSS), U35.47 (VSS), U36.1 (GND), U37.2 (GND), U38.2 (GND), U39.2 (GND), X1.2 (GND)
GNDA: C1.2, C4.2, NT7.1, R1.1, R4.2, R5.1, R7.2, R37.1
unnamed: C3.2, R4.1
unnamed: C23.1, L3.2, R16.1, R18.1, TP1.1
unnamed: C9.1, D2.2 (A), D3.2 (A), U3.21 (INTVCC)
unnamed: C6.2, D2.1 (K), U3.24 (BOOST1)
unnamed: C7.1, D3.1 (K), U3.18 (BOOST2)
unnamed: C21.2, D4.1 (K), L3.1, U6.6 (SW)
unnamed: D5.2 (A), R35.2
unnamed: D6.2 (A), R36.2
unnamed: F1.2, J1.1
unnamed: J4.1, R38.2
unnamed: J5.1, R39.2
unnamed: J6.A5 (CC1), R40.2
unnamed: J6.B5 (CC2), R42.2
unnamed: J6.A6 (D+), J6.B6 (D+), R27.2
unnamed: J6.A7 (D-), J6.B7 (D-), R26.2
unnamed: L1.2, NT1.1, R12.1
unnamed: L2.2, NT2.2, R13.1
unnamed: M1.4 (PWM), U37.4 (BY)
unnamed: M2.4 (PWM), U39.4 (BY)
unnamed: Q3.2 (G), U3.25 (TG1)
unnamed: C6.1, L1.1, Q3.1 (S), Q4.3 (D), U3.26 (SW1)
unnamed: Q4.2 (G), U3.23 (BG1)
unnamed: Q5.2 (G), U3.17 (TG2)
unnamed: C7.2, L2.1, Q5.1 (S), Q6.3 (D), U3.16 (SW2)
unnamed: Q6.2 (G), U3.19 (BG2)
unnamed: R6.1, U3.11 (DIFFOUT)
unnamed: R5.2, U3.29 (FREQ)
unnamed: R37.2, U3.12 (ISET)
unnamed: C1.1, C3.1, U3.3 (ITH)
unnamed: C5.2, R9.2, U3.31 (SENSE1+)
unnamed: C5.1, R8.1, U3.32 (SENSE1-)
unnamed: C8.1, R10.1, U3.7 (SENSE2+)
unnamed: C8.2, R11.1, U3.8 (SENSE2-)
unnamed: C4.1, U3.1 (TK/SS)
unnamed: R6.2, R7.1, U3.2 (VFB)
unnamed: C2.2, R3.2, U3.22 (VIN)
unnamed: C21.1, U6.1 (BS)
unnamed: R16.2, R17.1, U6.3 (FB)
unnamed: U19.23 (BO), U25.6 (BI)
unnamed: U19.21 (CLKO), U25.8 (CLKI)
unnamed: U19.20 (CO), U25.9 (CI)
unnamed: U19.24 (NRSTO), U25.5 (NRSTI)
unnamed: R20.1, U19.22 (RI), U25.7 (RO)
unnamed: C50.2, C56.1, U19.1 (VDD1_0)
unnamed: C62.2, C66.1, C93.1, U19.28 (VDD1_1), U25.1 (VDD1_0)
unnamed: C42.2, C50.1, U19.2 (VDD2_0)
unnamed: C66.2, C69.1, U19.27 (VDD2_1), U25.2 (VDD2_0)
unnamed: C35.2, C42.1, U19.3 (VDD3_0)
unnamed: C69.2, C71.1, U19.26 (VDD3_1), U25.3 (VDD3_0)
unnamed: U20.6 (BI), U25.23 (BO)
unnamed: U20.23 (BO), U26.6 (BI)
unnamed: U20.9 (CI), U25.20 (CO)
unnamed: U20.8 (CLKI), U25.21 (CLKO)
unnamed: U20.21 (CLKO), U26.8 (CLKI)
unnamed: U20.20 (CO), U26.9 (CI)
unnamed: U20.5 (NRSTI), U25.24 (NRSTO)
unnamed: U20.24 (NRSTO), U26.5 (NRSTI)
unnamed: R21.1, U20.22 (RI), U26.7 (RO)
unnamed: R23.1, U20.7 (RO), U25.22 (RI)
unnamed: C51.2, C57.1, U20.1 (VDD1_0)
unnamed: C63.2, C67.1, C94.1, U20.28 (VDD1_1), U26.1 (VDD1_0)
unnamed: C43.2, C51.1, U20.2 (VDD2_0)
unnamed: C67.2, C70.1, U20.27 (VDD2_1), U26.2 (VDD2_0)
unnamed: C36.2, C43.1, U20.3 (VDD3_0)
unnamed: C70.2, C72.1, U20.26 (VDD3_1), U26.3 (VDD3_0)
unnamed: C73.2, C75.1, U25.28 (VDD1_1)
unnamed: C75.2, C77.1, U25.27 (VDD2_1)
unnamed: C77.2, C79.1, U25.26 (VDD3_1)
unnamed: R22.1, U26.22 (RI)
unnamed: C74.2, C76.1, U26.28 (VDD1_1)
unnamed: C76.2, C78.1, U26.27 (VDD2_1)
unnamed: C78.2, C80.1, U26.26 (VDD3_1)
unnamed: R30.2, SW1.1, U35.44 (BOOT0)
unnamed: R43.2, U35.20 (PB2)
unnamed: U35.5 (PH0), X1.3 (OUT)

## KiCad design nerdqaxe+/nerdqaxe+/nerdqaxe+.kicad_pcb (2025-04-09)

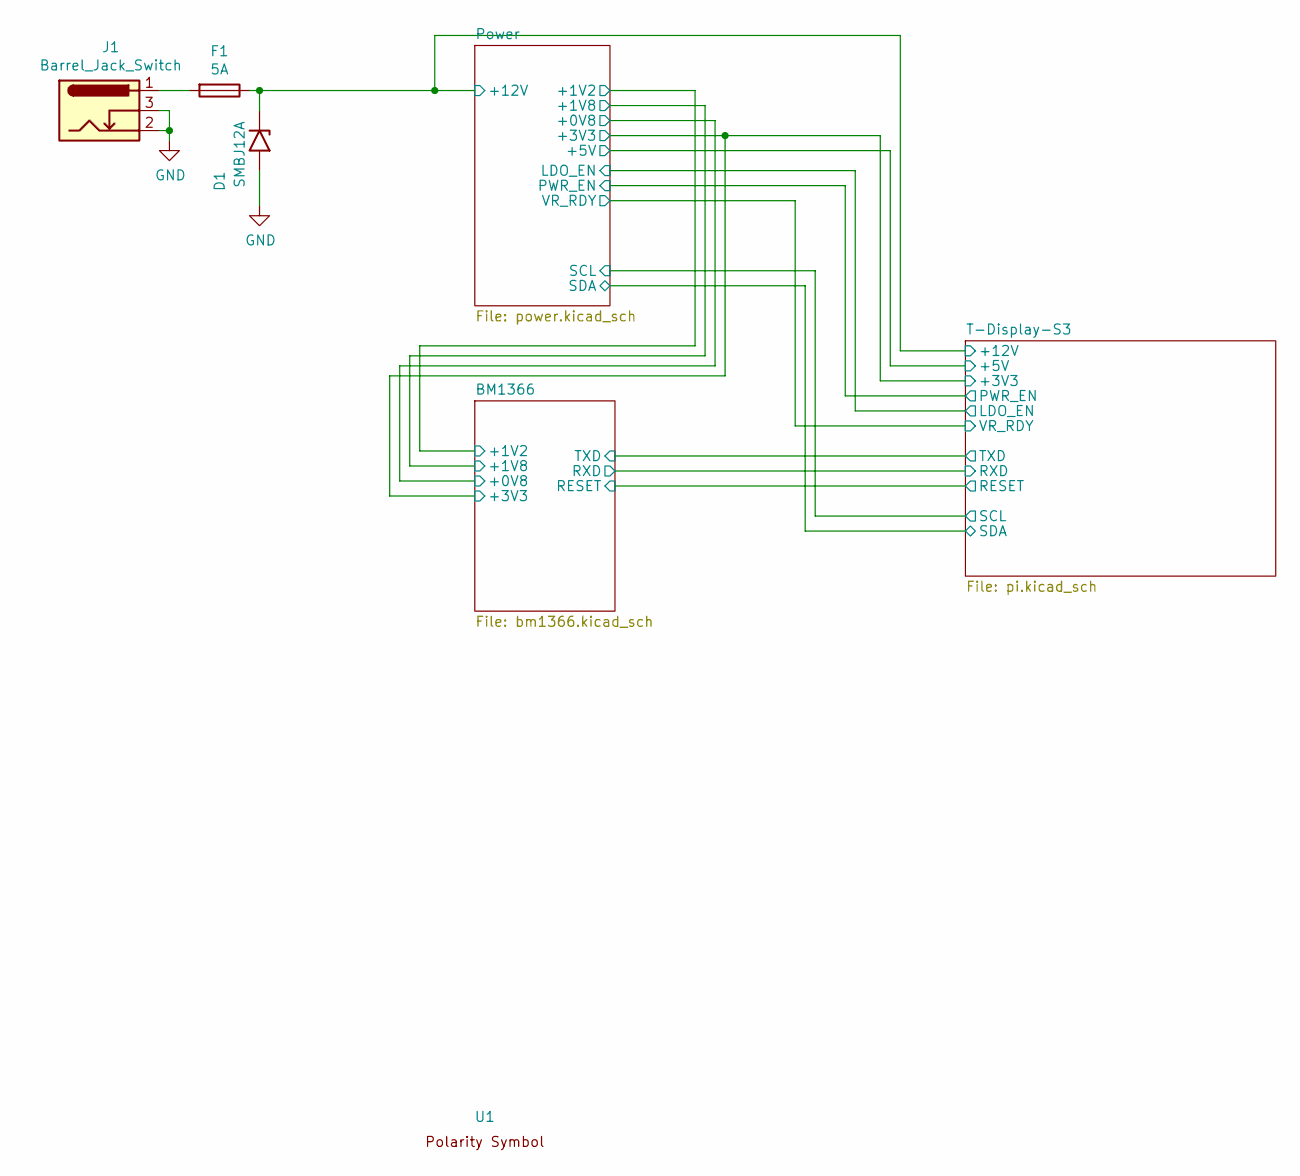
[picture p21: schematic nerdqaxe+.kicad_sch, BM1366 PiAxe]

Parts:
D1: SMBJ12A; D_SMB
F1: 5A; fuseholder_littlefuse_blok
J1: Barrel_Jack_Switch; BarrelJack_CUI_PJ-102AH_Horizontal
U1: polarity

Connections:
+12V: D1.1 (A1), F1.1; also elsewhere on the board
GND: D1.2 (A2), J1.2, J1.3; also elsewhere on the board
unnamed: F1.2, J1.1

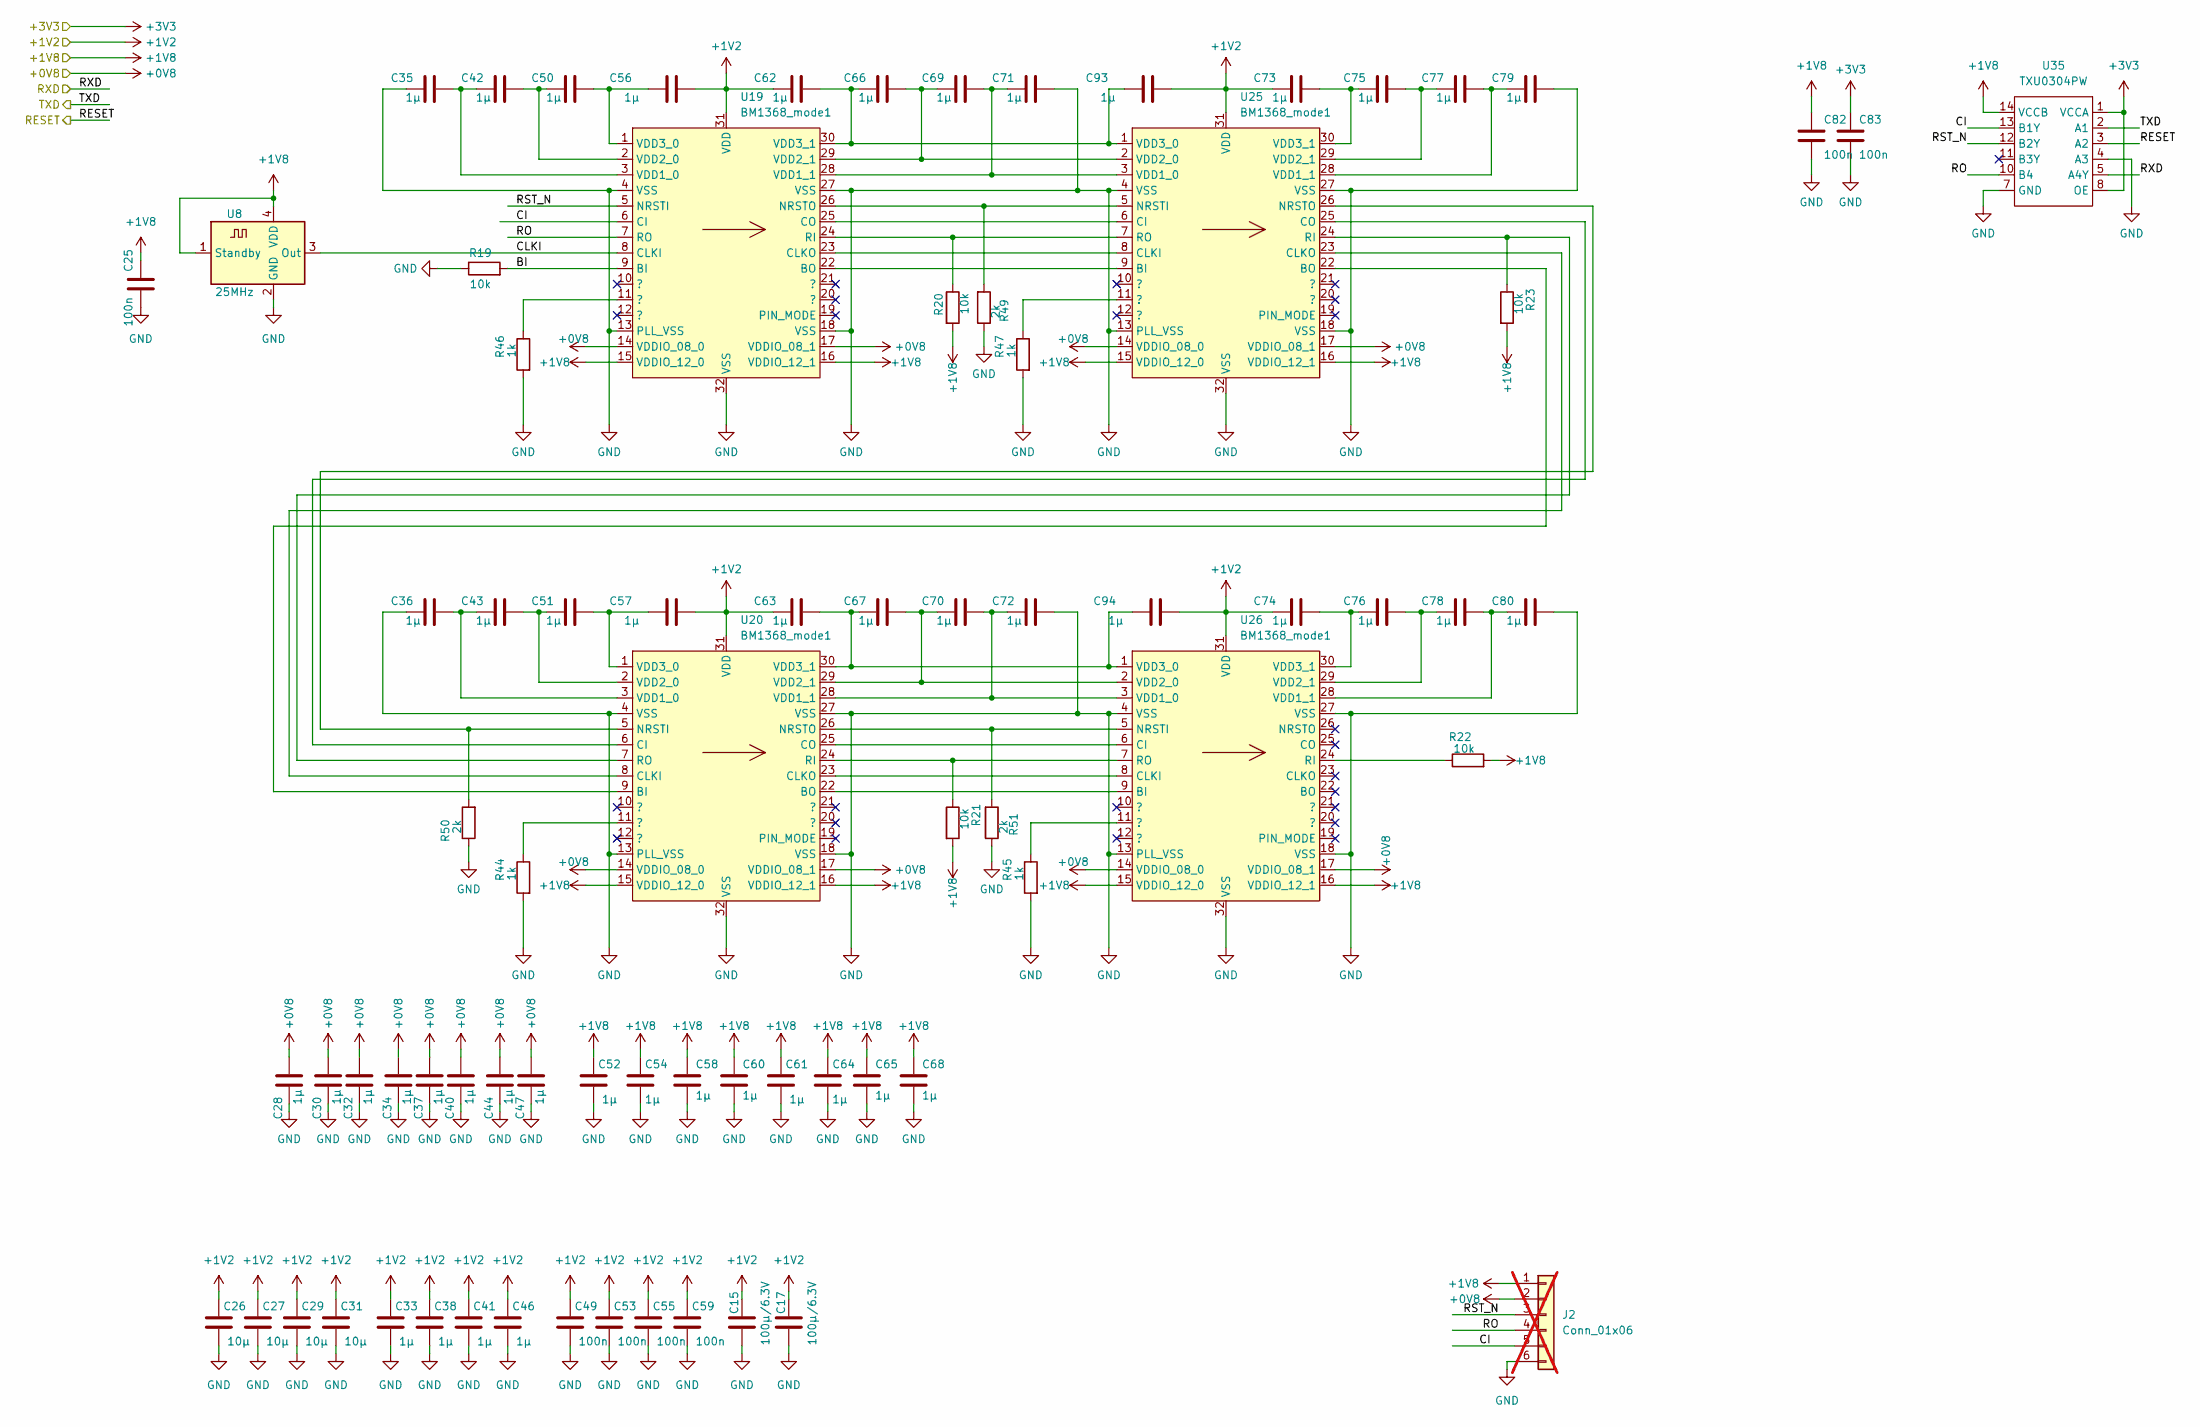
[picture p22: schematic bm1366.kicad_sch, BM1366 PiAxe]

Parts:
C15, C17: 100µ/6.3V; C_1210_3225Metric
C25, C49, C53, C55, C59, C82, C83: 100n; C_0805_2012Metric
C26, C27, C29, C31: 10µ; C_0805_2012Metric
C28, C30, C32, C33, C34, C35, C36, C37, C38, C40, C41, C42, C43, C44, C46, C47, C50, C51, C52, C54, C56, C57, C58, C60, C61, C62, C63, C64, C65, C66, C67, C68, C69, C70, C71, C72, C73, C74, C75, C76, C77, C78, C79, C80, C93, C94: 1µ; C_0805_2012Metric
J2: Conn_01x06; PinHeader_1x06_P1.27mm_Vertical; not fitted
R19, R20, R21, R22, R23: 10k; R_0805_2012Metric
R44, R45, R46, R47: 1k; R_0805_2012Metric
R49, R50, R51: 2k; R_0805_2012Metric
U8: 25MHz; Oscillator_SMD_EuroQuartz_XO32-4Pin_3.2x2.5mm
U19, U20, U25, U26: BM1368_mode1; bm1368-package-modified
U35: TXU0304PW; TSSOP-14_4.4x5mm_P0.65mm

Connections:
+0V8: C28.2, C30.2, C32.2, C34.2, C37.2, C40.2, C44.2, C47.2, J2.2, U19.14 (VDDIO_08_0), U19.17 (VDDIO_08_1), U20.14 (VDDIO_08_0), U20.17 (VDDIO_08_1), U25.14 (VDDIO_08_0), U25.17 (VDDIO_08_1), U26.14 (VDDIO_08_0), U26.17 (VDDIO_08_1); also elsewhere on the board
+1V2: C15.1, C17.1, C26.1, C27.1, C29.1, C31.1, C33.1, C38.1, C41.1, C46.1, C49.1, C53.1, C55.1, C56.2, C57.2, C59.1, C62.1, C63.1, C73.1, C74.1, C93.2, C94.2, U19.31 (VDD), U20.31 (VDD), U25.31 (VDD), U26.31 (VDD); also elsewhere on the board
+1V8: C25.1, C52.1, C54.1, C58.1, C60.1, C61.1, C64.1, C65.1, C68.1, C82.1, J2.1, R20.2, R21.2, R22.2, R23.2, U8.1 (Standby), U8.4 (VDD), U19.15 (VDDIO_12_0), U19.16 (VDDIO_12_1), U20.15 (VDDIO_12_0), U20.16 (VDDIO_12_1), U25.15 (VDDIO_12_0), U25.16 (VDDIO_12_1), U26.15 (VDDIO_12_0), U26.16 (VDDIO_12_1), U35.14 (VCCB); also elsewhere on the board
+3V3: C83.1, U35.1 (VCCA), U35.8 (OE); also elsewhere on the board
/BM1366/BI: R19.2, U19.9 (BI)
/BM1366/CI: J2.5, U19.6 (CI), U35.13 (B1Y)
/BM1366/CLKI: U8.3 (Out), U19.8 (CLKI)
/BM1366/RESET: U35.3 (A2); also elsewhere on the board
/BM1366/RO: J2.4, U19.7 (RO), U35.10 (B4)
/BM1366/RST_N: J2.3, U19.5 (NRSTI), U35.12 (B2Y)
/BM1366/RXD: U35.5 (A4Y); also elsewhere on the board
/BM1366/TXD: U35.2 (A1); also elsewhere on the board
GND: C15.2, C17.2, C25.2, C26.2, C27.2, C28.1, C29.2, C30.1, C31.2, C32.1, C33.2, C34.1, C35.1, C36.1, C37.1, C38.2, C40.1, C41.2, C44.1, C46.2, C47.1, C49.2, C52.2, C53.2, C54.2, C55.2, C58.2, C59.2, C60.2, C61.2, C64.2, C65.2, C68.2, C71.2, C72.2, C79.2, C80.2, C82.2, C83.2, J2.6, R19.1, R44.2, R45.2, R46.2, R47.2, R49.1, R50.1, R51.1, U8.2 (GND), U19.4 (VSS), U19.13 (PLL_VSS), U19.18 (VSS), U19.27 (VSS), U19.32 (VSS), U20.4 (VSS), U20.13 (PLL_VSS), U20.18 (VSS), U20.27 (VSS), U20.32 (VSS), U25.4 (VSS), U25.13 (PLL_VSS), U25.18 (VSS), U25.27 (VSS), U25.32 (VSS), U26.4 (VSS), U26.13 (PLL_VSS), U26.18 (VSS), U26.27 (VSS), U26.32 (VSS), U35.4 (A3), U35.7 (GND); also elsewhere on the board
unnamed: R44.1, U20.11 (?)
unnamed: R45.1, U26.11 (?)
unnamed: R46.1, U19.11 (?)
unnamed: R47.1, U25.11 (?)
unnamed: U19.22 (BO), U25.9 (BI)
unnamed: U19.23 (CLKO), U25.8 (CLKI)
unnamed: U19.25 (CO), U25.6 (CI)
unnamed: R49.2, U19.26 (NRSTO), U25.5 (NRSTI)
unnamed: R20.1, U19.24 (RI), U25.7 (RO)
unnamed: C35.2, C42.1, U19.3 (VDD1_0)
unnamed: C69.2, C71.1, U19.28 (VDD1_1), U25.3 (VDD1_0)
unnamed: C42.2, C50.1, U19.2 (VDD2_0)
unnamed: C66.2, C69.1, U19.29 (VDD2_1), U25.2 (VDD2_0)
unnamed: C50.2, C56.1, U19.1 (VDD3_0)
unnamed: C62.2, C66.1, C93.1, U19.30 (VDD3_1), U25.1 (VDD3_0)
unnamed: U20.9 (BI), U25.22 (BO)
unnamed: U20.22 (BO), U26.9 (BI)
unnamed: U20.6 (CI), U25.25 (CO)
unnamed: U20.8 (CLKI), U25.23 (CLKO)
unnamed: U20.23 (CLKO), U26.8 (CLKI)
unnamed: U20.25 (CO), U26.6 (CI)
unnamed: R50.2, U20.5 (NRSTI), U25.26 (NRSTO)
unnamed: R51.2, U20.26 (NRSTO), U26.5 (NRSTI)
unnamed: R21.1, U20.24 (RI), U26.7 (RO)
unnamed: R23.1, U20.7 (RO), U25.24 (RI)
unnamed: C36.2, C43.1, U20.3 (VDD1_0)
unnamed: C70.2, C72.1, U20.28 (VDD1_1), U26.3 (VDD1_0)
unnamed: C43.2, C51.1, U20.2 (VDD2_0)
unnamed: C67.2, C70.1, U20.29 (VDD2_1), U26.2 (VDD2_0)
unnamed: C51.2, C57.1, U20.1 (VDD3_0)
unnamed: C63.2, C67.1, C94.1, U20.30 (VDD3_1), U26.1 (VDD3_0)
unnamed: C77.2, C79.1, U25.28 (VDD1_1)
unnamed: C75.2, C77.1, U25.29 (VDD2_1)
unnamed: C73.2, C75.1, U25.30 (VDD3_1)
unnamed: R22.1, U26.24 (RI)
unnamed: C78.2, C80.1, U26.28 (VDD1_1)
unnamed: C76.2, C78.1, U26.29 (VDD2_1)
unnamed: C74.2, C76.1, U26.30 (VDD3_1)

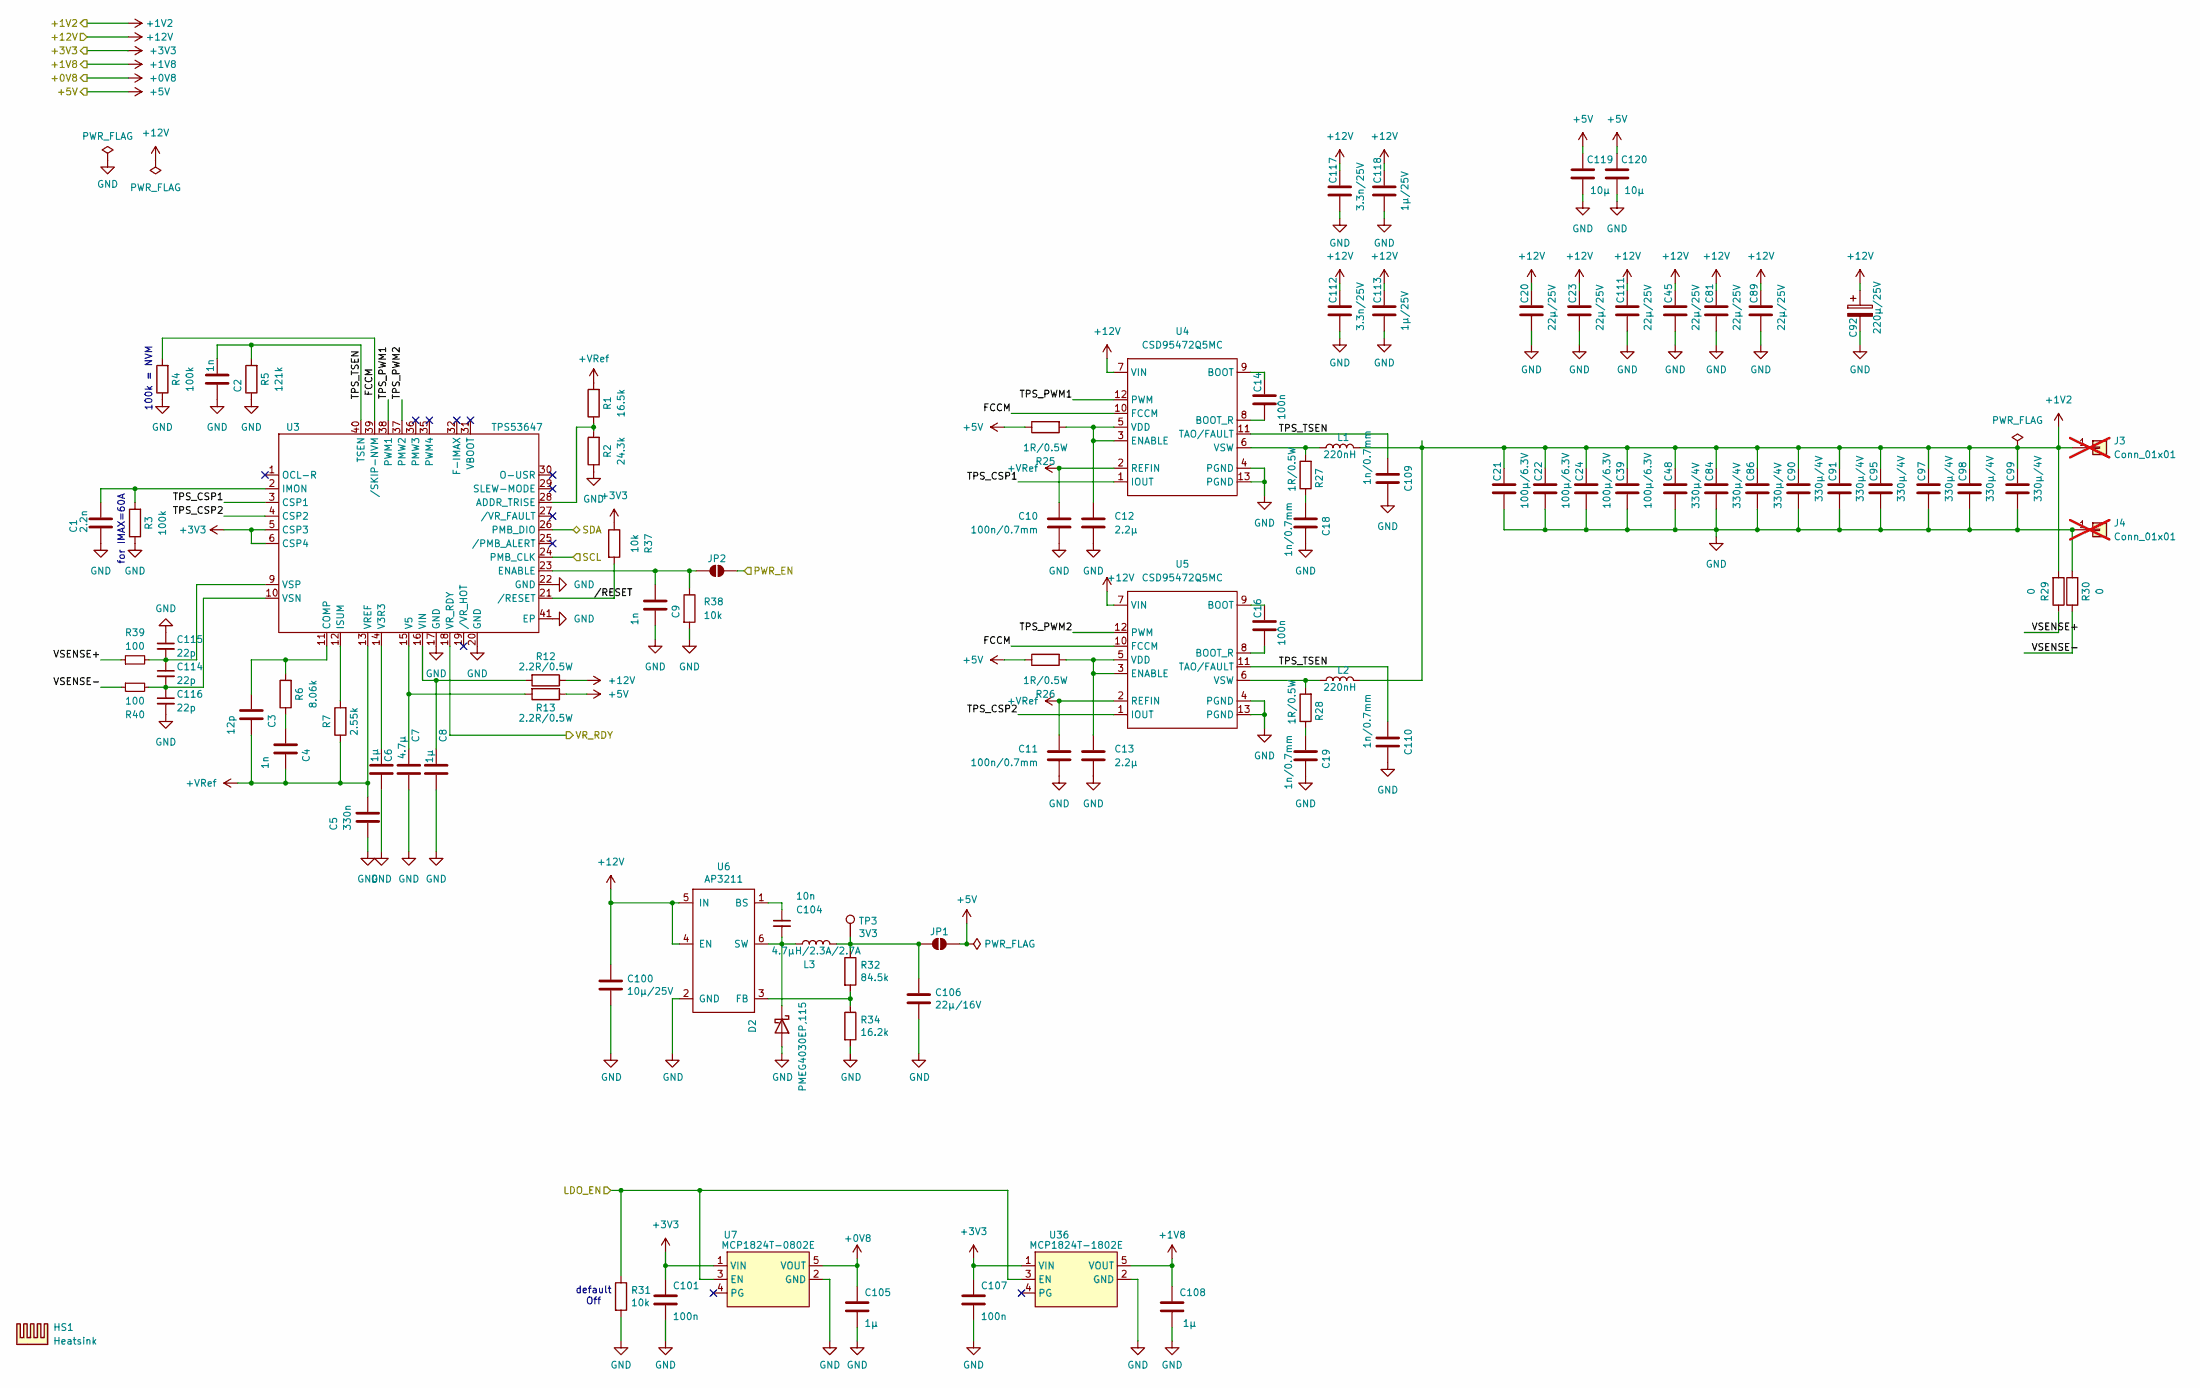
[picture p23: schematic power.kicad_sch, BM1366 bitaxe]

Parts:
C1: 2.2n; C_0805_2012Metric
C2, C4, C9: 1n; C_0805_2012Metric
C3: 12p; C_0603_1608Metric
C5: 330n; C_0805_2012Metric
C6, C8, C105, C108: 1µ; C_0805_2012Metric
C7: 4.7µ; C_0805_2012Metric
C10, C11: 100n/0.7mm; C_0805_2012Metric
C12, C13: 2.2µ; C_0805_2012Metric
C14, C16, C101, C107: 100n; C_0805_2012Metric
C18, C19, C109, C110: 1n/0.7mm; C_0805_2012Metric
C20, C23, C45, C81, C89, C111: 22µ/25V; C_1210_3225Metric
C21, C22, C24, C39: 100µ/6.3V; C_1210_3225Metric
C48, C84, C86, C90, C91, C95, C97, C98, C99: 330µ/4V; C_1210_3225Metric
C92: 220µ/25V; CP_Elec_8x10
C100: 10µ/25V; C_0805_2012Metric
C104: 10n; C_0805_2012Metric
C106: 22µ/16V; C_1206_3216Metric
C112, C117: 3.3n/25V; C_0805_2012Metric
C113, C118: 1µ/25V; C_0805_2012Metric
C114, C115, C116: 22p; C_0603_1608Metric
C119, C120: 10µ; C_0805_2012Metric
D2: PMEG4030EP,115; D_SOD-128
HS1: Heatsink
J3, J4: Conn_01x01; Wuerth_REDCUBE-THR_WP-THRBU_74650194_THR; not fitted
JP1, JP2: SolderJumper_2_Open; SolderJumper-2_P1.3mm_Open_RoundedPad1.0x1.5mm
L1, L2: 220nH; IFLR-4031GC-01-8x10
L3: 4.7µH/2.3A/2.7A; L_Taiyo-Yuden_NR-50xx
R1: 16.5k; R_0805_2012Metric
R2: 24.3k; R_0805_2012Metric
R3, R4: 100k; R_0805_2012Metric
R5: 121k; R_0805_2012Metric
R6: 8.06k; R_0805_2012Metric
R7: 2.55k; R_0805_2012Metric
R12, R13: 2.2R/0.5W; R_0805_2012Metric
R25, R26, R27, R28: 1R/0.5W; R_0805_2012Metric
R29, R30: 0; R_0805_2012Metric
R31, R37, R38: 10k; R_0805_2012Metric
R32: 84.5k; R_0805_2012Metric
R34: 16.2k; R_0805_2012Metric
R39, R40: 100; R_0805_2012Metric
TP3: 3V3; TestPoint_Pad_2.0x2.0mm
U3: TPS53647; Texas_RHA0040B_VQFN-40-1EP_6x6mm_P0.5mm_EP4.15x4.15mm_Therm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
U4, U5: CSD95472Q5MC; CSD95472-SON-5x6
U6: AP3211; SOT-23-6
U7: MCP1824T-0802E; SOT-23-5
U36: MCP1824T-1802E; SOT-23-5

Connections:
+0V8: C105.1, U7.5 (VOUT); also elsewhere on the board
+1V2: C21.1, C22.1, C24.1, C39.1, C48.1, C84.1, C86.1, C90.1, C91.1, C95.1, C97.1, C98.1, C99.1, J3.1, L1.2, L2.2, R29.2; also elsewhere on the board
+1V8: C108.1, U36.5 (VOUT); also elsewhere on the board
+3V3: C101.1, C107.1, R37.1, U3.5 (CSP3), U3.6 (CSP4), U7.1 (VIN), U36.1 (VIN); also elsewhere on the board
+5V: C119.1, C120.1, JP1.2 (B), R13.1, R25.1, R26.1; also elsewhere on the board
+12V: C20.1, C23.1, C45.1, C81.1, C89.1, C92.1, C100.1, C111.1, C112.1, C113.1, C117.1, C118.1, R12.1, U4.7 (VIN), U5.7 (VIN), U6.4 (EN), U6.5 (IN); also elsewhere on the board
+VRef: C3.2, C4.2, C5.1, C10.1, C11.1, R1.2, R7.1, U3.13 (VREF), U4.2 (REFIN), U5.2 (REFIN)
/Power/FCCM: R4.2, U3.39 (/SKIP-NVM), U4.10 (FCCM), U5.10 (FCCM)
/Power/LDO_EN: R31.1, U7.3 (EN), U36.3 (EN); also elsewhere on the board
/Power/PWR_EN: JP2.2 (B); also elsewhere on the board
/Power/TPS_CSP1: U3.3 (CSP1), U4.1 (IOUT)
/Power/TPS_CSP2: U3.4 (CSP2), U5.1 (IOUT)
/Power/TPS_PWM1: U3.38 (PWM1), U4.12 (PWM)
/Power/TPS_PWM2: U3.37 (PMW2), U5.12 (PWM)
/Power/TPS_TSEN: C2.1, C109.1, C110.1, R5.2, U3.40 (TSEN), U4.11 (TAO/FAULT), U5.11 (TAO/FAULT)
/Power/VR_RDY: U3.18 (VR_RDY); also elsewhere on the board
/Power/VSENSE+: R29.1, R39.1
/Power/VSENSE-: R30.1, R40.1
/Power//RESET: R37.2, U3.21 (/RESET)
/T-Display-S3/SCL: U3.24 (PMB_CLK); also elsewhere on the board
/T-Display-S3/SDA: U3.26 (PMB_DIO); also elsewhere on the board
GND: C1.2, C2.2, C5.2, C6.2, C7.1, C8.1, C9.2, C10.2, C11.2, C12.2, C13.2, C18.2, C19.2, C20.2, C21.2, C22.2, C23.2, C24.2, C39.2, C45.2, C48.2, C81.2, C84.2, C86.2, C89.2, C90.2, C91.2, C92.2, C95.2, C97.2, C98.2, C99.2, C100.2, C101.2, C105.2, C106.2, C107.2, C108.2, C109.2, C110.2, C111.2, C112.2, C113.2, C115.1, C116.2, C117.2, C118.2, C119.2, C120.2, D2.2 (A), J4.1, R2.1, R3.1, R4.1, R5.1, R30.2, R31.2, R34.2, R38.2, U3.17 (GND), U3.20 (GND), U3.22 (GND), U3.41 (EP), U4.4 (PGND), U4.13 (PGND), U5.4 (PGND), U5.13 (PGND), U6.2 (GND), U7.2 (GND), U36.2 (GND); also elsewhere on the board
unnamed: C4.1, R6.1
unnamed: C18.1, R27.1
unnamed: C19.1, R28.1
unnamed: C104.2, D2.1 (K), L3.1, U6.6 (SW)
unnamed: C106.1, JP1.1 (A), L3.2, R32.1, TP3.1
unnamed: C9.1, JP2.1 (A), R38.1, U3.23 (ENABLE)
unnamed: R1.1, R2.2, U3.28 (ADDR_TRISE)
unnamed: C3.1, R6.2, U3.11 (COMP)
unnamed: C1.1, R3.2, U3.2 (IMON)
unnamed: R7.2, U3.12 (ISUM)
unnamed: C6.1, U3.14 (V3R3)
unnamed: C7.2, R13.2, U3.15 (V5)
unnamed: C8.2, R12.2, U3.16 (VIN)
unnamed: C114.2, C116.1, R40.2, U3.10 (VSN)
unnamed: C114.1, C115.2, R39.2, U3.9 (VSP)
unnamed: C14.1, U4.9 (BOOT)
unnamed: C14.2, U4.8 (BOOT_R)
unnamed: C12.1, R25.2, U4.3 (ENABLE), U4.5 (VDD)
unnamed: L1.1, R27.2, U4.6 (VSW)
unnamed: C16.1, U5.9 (BOOT)
unnamed: C16.2, U5.8 (BOOT_R)
unnamed: C13.1, R26.2, U5.3 (ENABLE), U5.5 (VDD)
unnamed: L2.1, R28.2, U5.6 (VSW)
unnamed: C104.1, U6.1 (BS)
unnamed: R32.2, R34.1, U6.3 (FB)

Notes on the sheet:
default Off
for IMAX=60A
100k = NVM

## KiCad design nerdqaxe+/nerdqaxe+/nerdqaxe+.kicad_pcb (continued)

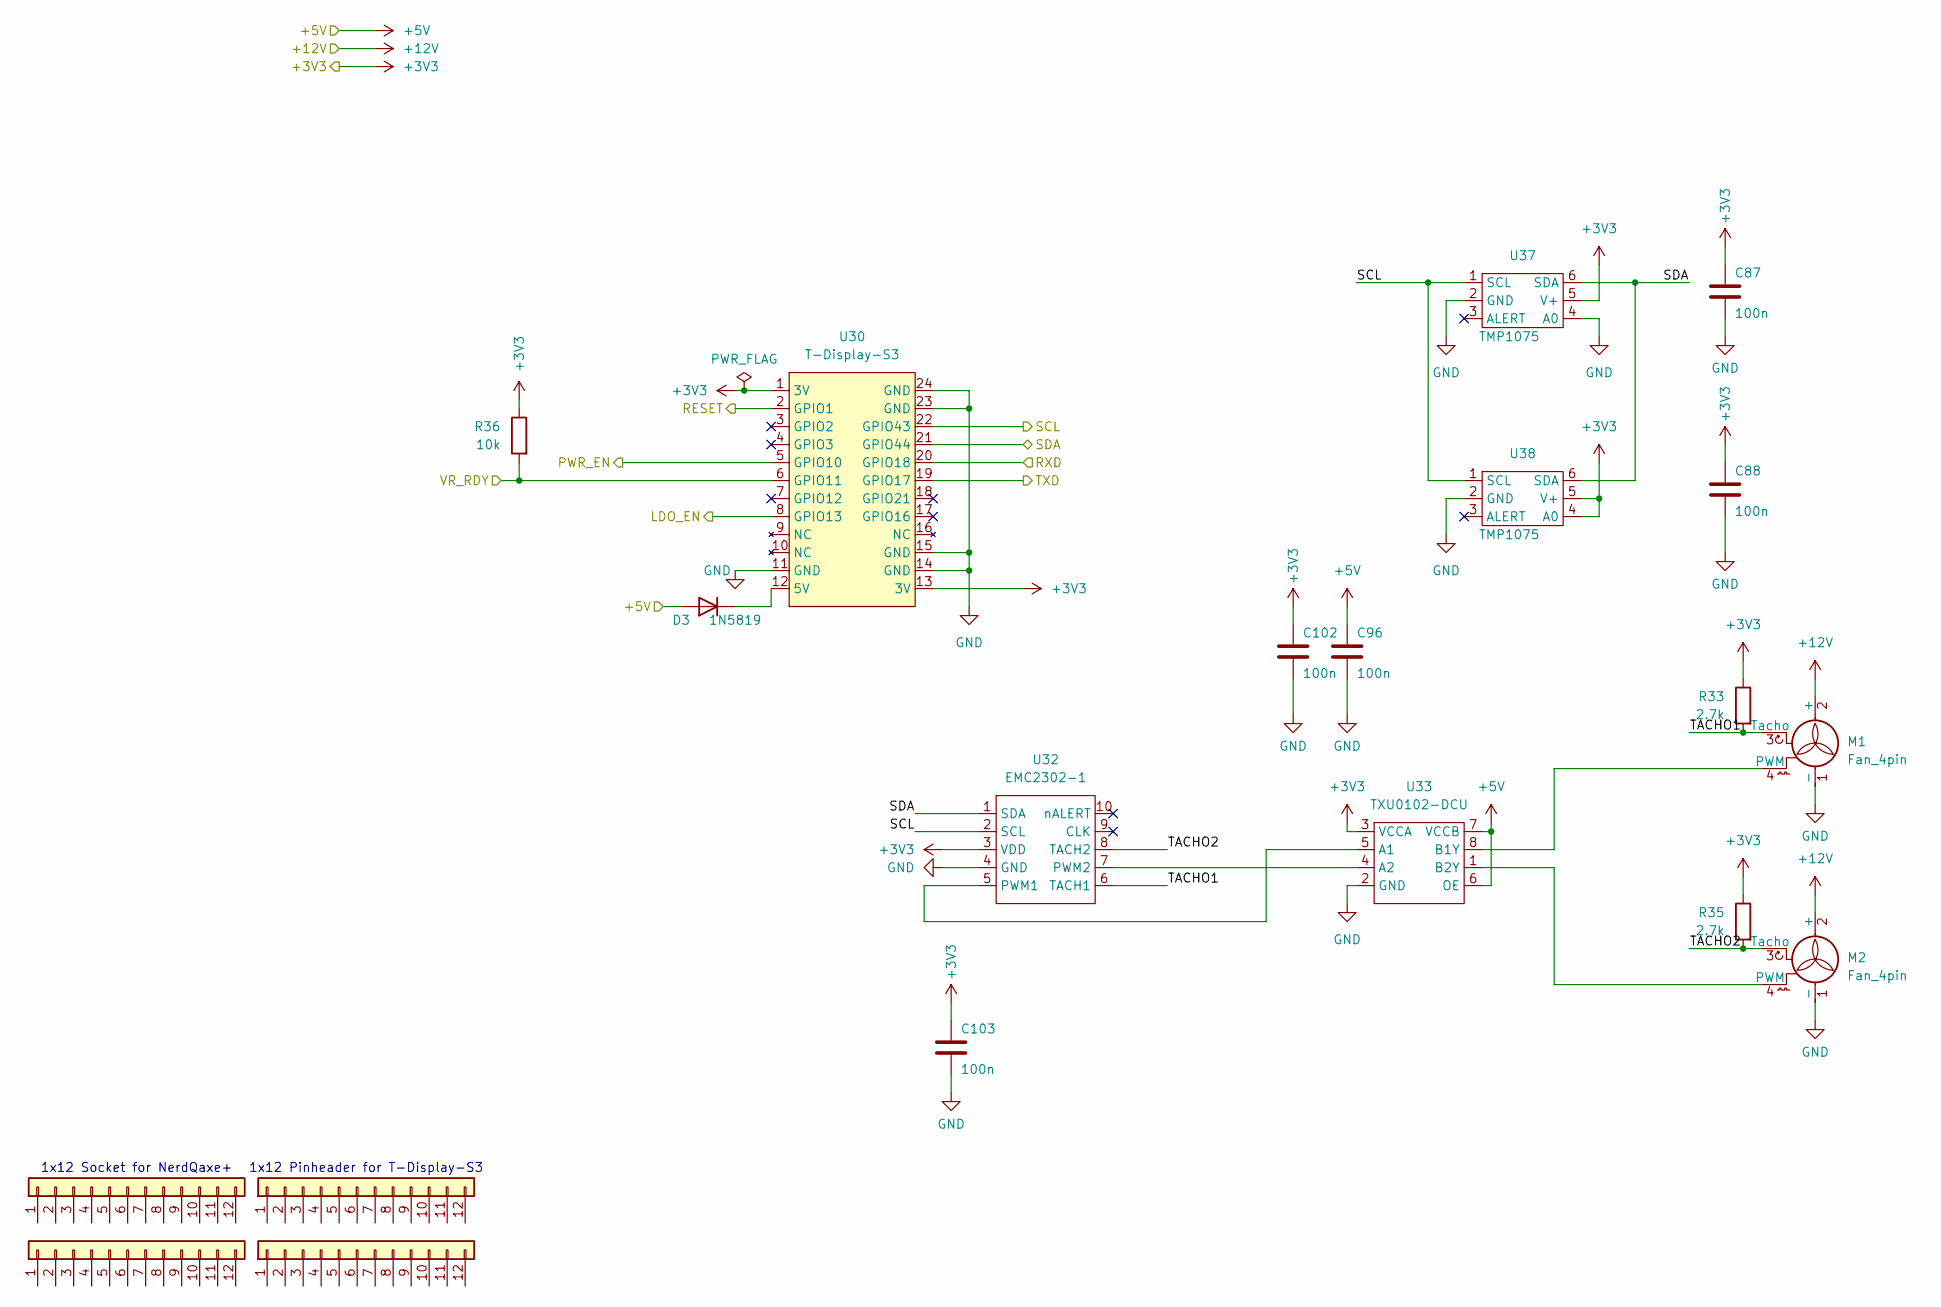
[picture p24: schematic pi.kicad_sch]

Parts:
C87, C88, C96, C102, C103: 100n; C_0805_2012Metric
D3: 1N5819; D_SOD-123
J5, J6: Conn_01x12-Socket
J7, J8: Conn_01x12-Header
M1, M2: Fan_4pin; FanPinHeader_1x04_P2.54mm_Vertical
R33, R35: 2.7k; R_0805_2012Metric
R36: 10k; R_0805_2012Metric
U30: T-Display-S3
U32: EMC2302-1; MSOP-10_3x3mm_P0.5mm
U33: TXU0102-DCU; VSSOP-8_2.3x2mm_P0.5mm
U37, U38: TMP1075; TMP1075-DRL

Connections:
+3V3: C87.1, C88.1, C102.1, C103.1, R33.1, R35.1, R36.1, U30.1 (3V), U30.13 (3V), U32.3 (VDD), U33.3 (VCCA), U37.5 (V+), U38.4 (A0), U38.5 (V+); also elsewhere on the board
+5V: C96.1, D3.2 (A), U33.6 (OE), U33.7 (VCCB); also elsewhere on the board
+12V: M1.2 (+), M2.2 (+); also elsewhere on the board
/BM1366/RESET: U30.2 (GPIO1); also elsewhere on the board
/BM1366/RXD: U30.20 (GPIO18); also elsewhere on the board
/BM1366/TXD: U30.19 (GPIO17); also elsewhere on the board
/Power/LDO_EN: U30.8 (GPIO13); also elsewhere on the board
/Power/PWR_EN: U30.5 (GPIO10); also elsewhere on the board
/Power/VR_RDY: R36.2, U30.6 (GPIO11); also elsewhere on the board
/T-Display-S3/SCL: U30.22 (GPIO43), U32.2 (SCL), U37.1 (SCL), U38.1 (SCL); also elsewhere on the board
/T-Display-S3/SDA: U30.21 (GPIO44), U32.1 (SDA), U37.6 (SDA), U38.6 (SDA); also elsewhere on the board
/T-Display-S3/TACHO1: M1.3 (Tacho), R33.2, U32.6 (TACH1)
/T-Display-S3/TACHO2: M2.3 (Tacho), R35.2, U32.8 (TACH2)
GND: C87.2, C88.2, C96.2, C102.2, C103.2, M1.1 (-), M2.1 (-), U30.11 (GND), U30.14 (GND), U30.15 (GND), U30.23 (GND), U30.24 (GND), U32.4 (GND), U33.2 (GND), U37.2 (GND), U37.4 (A0), U38.2 (GND); also elsewhere on the board
unnamed: D3.1 (K), U30.12 (5V)
unnamed: M1.4 (PWM), U33.8 (B1Y)
unnamed: M2.4 (PWM), U33.1 (B2Y)
unnamed: U32.5 (PWM1), U33.5 (A1)
unnamed: U32.7 (PWM2), U33.4 (A2)

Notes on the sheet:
1x12 Socket for NerdQaxe+
1x12 Pinheader for T-Display-S3

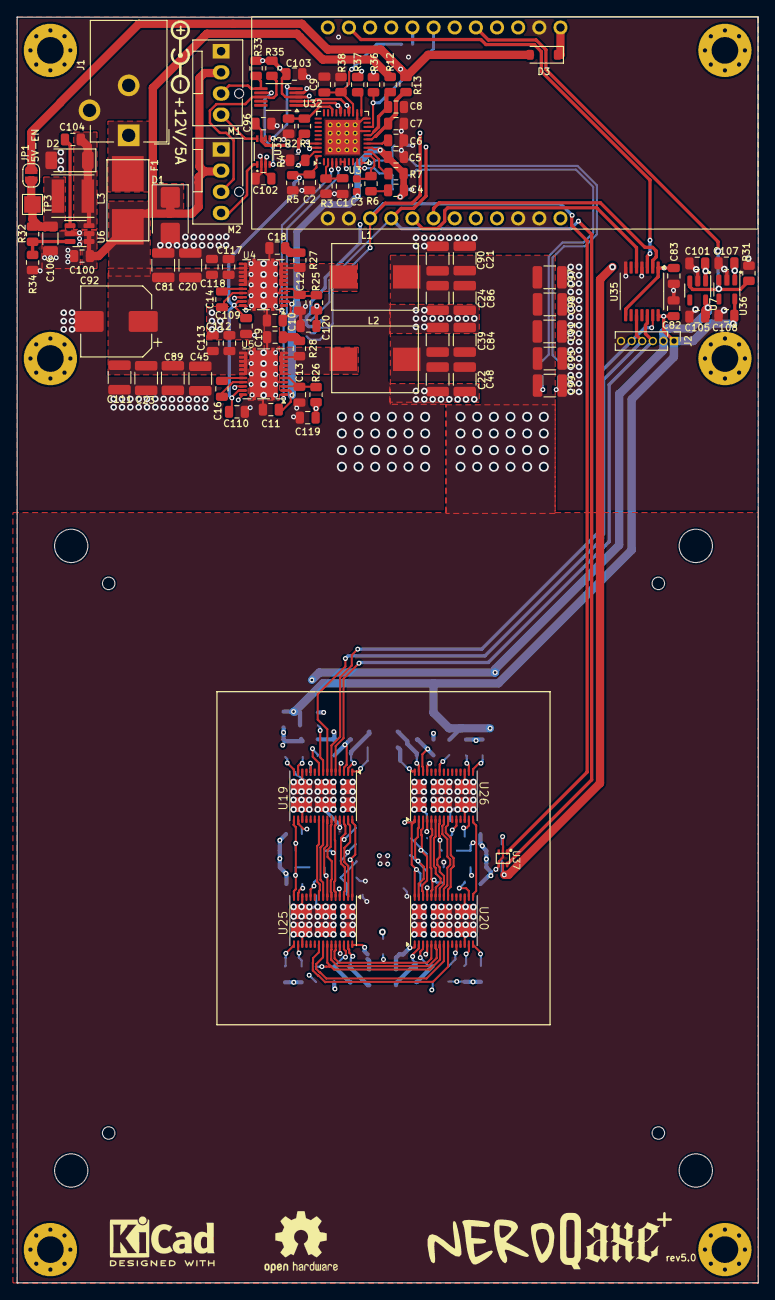
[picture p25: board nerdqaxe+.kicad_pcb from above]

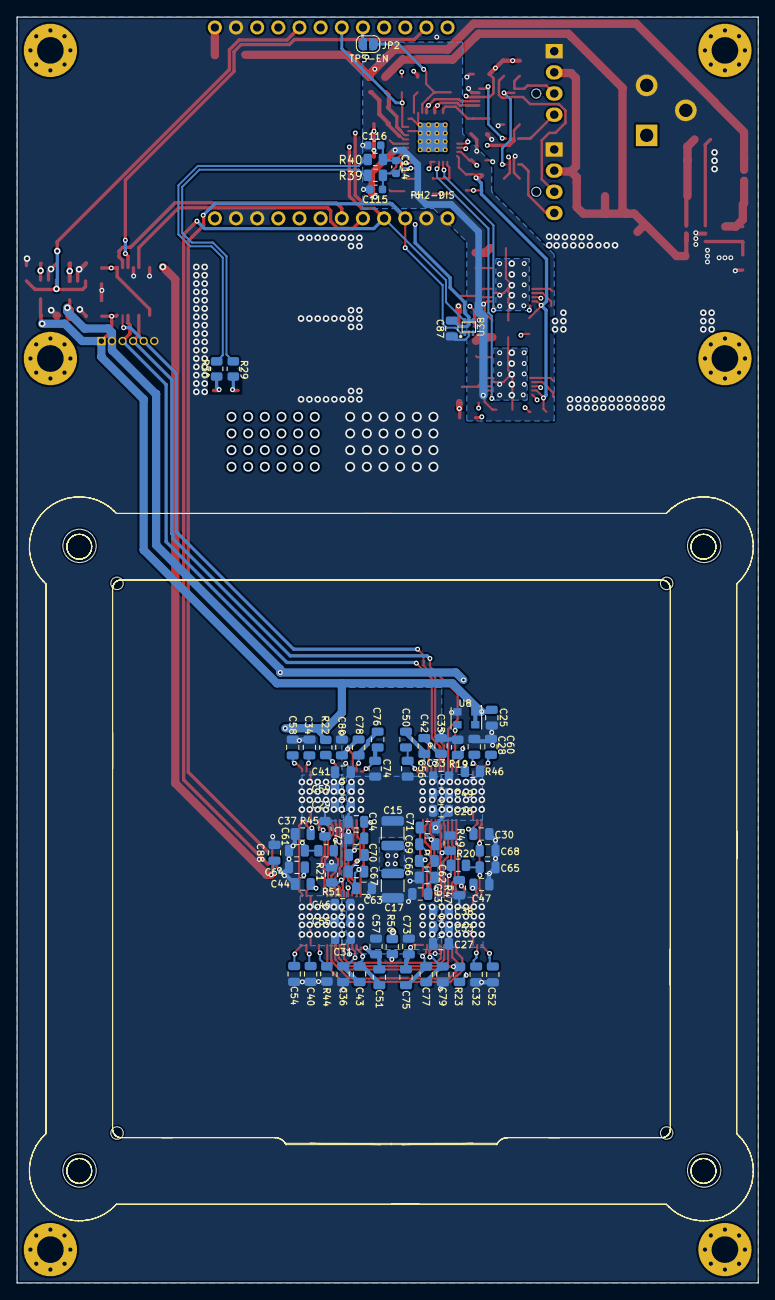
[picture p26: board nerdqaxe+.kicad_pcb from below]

Board: 4 copper layers, 89.0 x 152.0 mm, 188 parts (81 on the bottom side), 101 nets.

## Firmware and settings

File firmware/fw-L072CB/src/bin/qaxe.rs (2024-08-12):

#![no_std]
#![no_main]

use core::option::Option::Some;
use defmt::{panic, *};
use defmt_rtt as _; // global logger
use embassy_executor::Spawner;
use embassy_stm32::gpio::{Input, Level, Output, OutputType, Pull, Speed};
use embassy_stm32::i2c;
use embassy_stm32::i2c::I2c;
use embassy_stm32::rcc::*;
use embassy_stm32::time::{khz, Hertz};
use embassy_stm32::timer::simple_pwm::{PwmPin, SimplePwm};
use embassy_stm32::timer::Channel as PWMChannel;
use embassy_stm32::usart::BufferedUart;
use embassy_stm32::usb::{Driver, Instance};
use embassy_stm32::{bind_interrupts, peripherals, usart, usb, Config};
use embassy_sync::blocking_mutex::raw::{CriticalSectionRawMutex, ThreadModeRawMutex};
use embassy_sync::channel::Channel;
use embassy_sync::mutex::Mutex;
use embassy_sync::signal::Signal;
use embassy_time::Timer;
use embedded_io_async::Read;
use embassy_stm32::rcc::mux::Clk48sel;

mod uid;

use embassy_stm32::timer::low_level::OutputPolarity;
use embassy_usb::class::cdc_acm::{CdcAcmClass, State};
use embassy_usb::driver::EndpointError;
use embassy_usb::Builder;
use embedded_io_async::Write;
use futures::future::join4;
use panic_probe as _;

extern crate alloc;
extern crate alloc_cortex_m;

mod protobuf;
use protobuf::coms::{QControl, QRequest, QResponse, QState};
use quick_protobuf::{self, MessageWrite};

use alloc::borrow::Cow;

use alloc_cortex_m::CortexMHeap;

#[global_allocator]
static ALLOCATOR: CortexMHeap = CortexMHeap::empty();

bind_interrupts!(struct Irqs {
    USB => usb::InterruptHandler<peripherals::USB>;
    USART1 => usart::BufferedInterruptHandler<peripherals::USART1>;
    I2C2 => i2c::EventInterruptHandler<peripherals::I2C2>, i2c::ErrorInterruptHandler<peripherals::I2C2>;
});
use embassy_stm32::peripherals::*;

#[derive(PartialEq)]
enum ResetManagerCommand {
    Reset,
    Shutdown,
}

static RESET_MANAGER_SIGNAL: Signal<CriticalSectionRawMutex, ResetManagerCommand> = Signal::new();

static PGOOD: Mutex<ThreadModeRawMutex, bool> = Mutex::new(false);

static TEMP1: Mutex<ThreadModeRawMutex, u16> = Mutex::new(0u16);
static TEMP2: Mutex<ThreadModeRawMutex, u16> = Mutex::new(0u16);

struct PWMControl {
    pwm1_value: u16,
    pwm2_value: u16,
}

static PWM_CTRL_CHANNEL: Channel<ThreadModeRawMutex, PWMControl, 1> = Channel::new();

const RX_BUF_SIZE : usize = 256;
const TX_BUF_SIZE : usize = 256;

#[embassy_executor::main]
async fn main(spawner: Spawner) {
    info!("Hello World!");


    // Initialize the allocator before using it
    let start = cortex_m_rt::heap_start() as usize;
    let size = 1024;
    unsafe { ALLOCATOR.init(start, size) }

    let mut config = Config::default();
    config.rcc.hsi48 = Some(Hsi48Config {
        sync_from_usb: true,
    }); // needed for USB
    config.rcc.sys = Sysclk::PLL1_R;
    config.rcc.hsi = true;
    config.rcc.pll = Some(Pll {
        source: PllSource::HSI,
        div: PllDiv::DIV3,
        mul: PllMul::MUL6,
    });
    config.rcc.mux.clk48sel = Clk48sel::HSI48;

    let p = embassy_stm32::init(config);

    let driver = Driver::new(p.USB, Irqs, p.PA12, p.PA11);

    // Create embassy-usb Config
    let mut config = embassy_usb::Config::new(0xc0de, 0xcaff);
    config.max_packet_size_0 = 64;
    config.manufacturer = Some("Microengineer");
    config.product = Some("Qaxe");
    config.serial_number = Some(uid::uid_hex());
    config.self_powered = true;

    // Required for windows compatibility.
    // https://developer.nordicsemi.com/nRF_Connect_SDK/doc/1.9.1/kconfig/CONFIG_CDC_ACM_IAD.html#help
    config.device_class = 0xEF;
    config.device_sub_class = 0x02;
    config.device_protocol = 0x01;
    config.composite_with_iads = true;

    // Create embassy-usb DeviceBuilder using the driver and config.
    // It needs some buffers for building the descriptors.
    let mut config_descriptor = [0; 256];
    let mut bos_descriptor = [0; 256];
    let mut control_buf = [0; 64];

    let mut state_usb_asic = State::new();
    let mut state_usb_ctrl = State::new();

    let mut builder = Builder::new(
        driver,
        config,
        &mut config_descriptor,
        &mut bos_descriptor,
        &mut [], // no msos descriptors
        &mut control_buf,
    );

    // Create classes on the builder.
    let class_usb_asic = CdcAcmClass::new(&mut builder, &mut state_usb_asic, 64);
    let (mut sender, mut receiver) = class_usb_asic.split();

    let mut class_usb_ctrl = CdcAcmClass::new(&mut builder, &mut state_usb_ctrl, 64);

    // Build the builder.
    let mut usb = builder.build();

    let mut config = usart::Config::default();
    config.baudrate = 115200;

    let mut tx_buf = [0u8; TX_BUF_SIZE];
    let mut rx_buf = [0u8; RX_BUF_SIZE];

    let usart = BufferedUart::new(p.USART1, Irqs, p.PA10, p.PA9, &mut tx_buf, &mut rx_buf, config).unwrap();
    let (mut tx_ctrl, mut rx_ctrl) = usart.split();

    // Run the USB device.
    let usb_fut = usb.run();

    let run_1v2 = Output::new(p.PA2, Level::Low, Speed::Low);
    let pgood_1v2 = Input::new(p.PA3, Pull::None);
    let pgood_led = Output::new(p.PA5, Level::High, Speed::Low);
    let mut activity_led = Output::new(p.PA4, Level::High, Speed::Low);

    // init ldo_en with low
    let ldo_en = Output::new(p.PA7, Level::Low, Speed::Low);

    let reset = Output::new(p.PB13, Level::High, Speed::Low);

    let ch1 = PwmPin::new_ch1(p.PA0, OutputType::PushPull);
    let ch2 = PwmPin::new_ch2(p.PA1, OutputType::PushPull);
    let mut pwm1 = SimplePwm::new(
        p.TIM2,
        Some(ch1),
        Some(ch2),
        None,
        None,
        khz(10),
        Default::default(),
    );
    pwm1.set_polarity(PWMChannel::Ch1, OutputPolarity::ActiveHigh);
    pwm1.set_polarity(PWMChannel::Ch2, OutputPolarity::ActiveHigh);
    pwm1.set_duty(PWMChannel::Ch1, pwm1.get_max_duty());
    pwm1.set_duty(PWMChannel::Ch2, pwm1.get_max_duty());
    pwm1.enable(PWMChannel::Ch1);
    pwm1.enable(PWMChannel::Ch2);

    let mut i2c_config = embassy_stm32::i2c::Config::default();
    i2c_config.scl_pullup = true;
    i2c_config.sda_pullup = true;

    let i2c = I2c::new(
        p.I2C2,
        p.PB10,
        p.PB11,
        Irqs,
        p.DMA1_CH4,
        p.DMA1_CH5,
        Hertz(100_000),
        i2c_config, /*Default::default()*/
    );

    unwrap!(spawner.spawn(reset_manager(run_1v2, reset, ldo_en)));
    unwrap!(spawner.spawn(power_good_task(pgood_1v2, pgood_led)));
    unwrap!(spawner.spawn(pwm_manager(pwm1)));
    unwrap!(spawner.spawn(temp_manager(i2c)));

    let protobuf_rpc_fut = async {
        loop {
            class_usb_ctrl.wait_connection().await;
            info!("Connected");
            let _ = json_rpc(&mut class_usb_ctrl).await;
            info!("Disconnected");
        }
    };

    let relay_receiver_fut = async {
        loop {
            let mut usb_buf = [0; 64];
            receiver.wait_connection().await;
            info!("Connected relay receiver");

            loop {
                let usb_read = match receiver.read_packet(&mut usb_buf).await {
                    Ok(n) => n,
                    Err(e) => {
                        error!("Error reading from USB: {:?}", e);
                        break;
                    }
                };

                if usb_read == 0 {
                    continue; // No data read, continue the loop
                }

                debug!("USB -> USART: {:x}", &usb_buf[..usb_read]);

                if let Err(e) = tx_ctrl.write_all(&usb_buf[..usb_read]).await {
                    error!("Error writing to USART: {:?}", e);
                    break;
                }
            }
        }
    };

    let relay_sender_fut = async {
        loop {
            sender.wait_connection().await;

            info!("Connected relay sender");

            let mut toggle = 0;
            let mut num_bytes = 0;
            let mut received = [0u8;11];
            let preample = [0xaa, 0x55];
            loop {
                let mut byte = [0u8;1];
                match rx_ctrl.read_exact(&mut byte).await {
                    Ok(_) => (),
                    Err(e) => {
                        error!("Error reading from USART: {:?}", e);
                    }
                };

                received[num_bytes] = byte[0];

                // try to sync on serial data
                match num_bytes {
                    0 | 1 => // wait for 0xaa 0x55
                        if received[num_bytes] != preample[num_bytes] {
                            debug!("unexpected start of serial data, trying to resync ...");
                            num_bytes = 0;
                            continue;
                        },
                    _ => {},
                };

                num_bytes += 1;

                if num_bytes != 11 {
                    continue;
                }
                num_bytes = 0;

                // toggle led with each response received
                toggle = 1 - toggle;
                match toggle {
                    0 => activity_led.set_high(),
                    1 => activity_led.set_low(),
                    _ => {}
                };

                debug!("USART -> USB: {:x}", &received[..]);
                if let Err(e) = sender.write_packet(&received[..]).await {
                    error!("Error writing to USB: {:?}", e);
                    break;
                }
            }
        }
    };

    let _ = join4(
        usb_fut,
        protobuf_rpc_fut,
        relay_receiver_fut,
        relay_sender_fut,
    )
    .await;
}

#[embassy_executor::task]
async fn power_good_task(pgood_1v2: Input<'static>, mut pgood_led: Output<'static>) {
    loop {
        let mut pgood_state = PGOOD.lock().await;
        if pgood_1v2.is_high() {
            *pgood_state = true;
            pgood_led.set_low();
        } else {
            *pgood_state = false;
            pgood_led.set_high();
        }
        drop(pgood_state);
        Timer::after_millis(500).await;
    }
}

#[embassy_executor::task]
async fn reset_manager(mut run_1v2: Output<'static>, mut reset: Output<'static>, mut ldo_en: Output<'static>) {
    loop {
        let signal = RESET_MANAGER_SIGNAL.wait().await;

        match signal {
            ResetManagerCommand::Reset => {
                info!("reset triggered!");
                // switch off all LDOs and assert reset
                run_1v2.set_low();
                ldo_en.set_low();
                reset.set_high();
                Timer::after_millis(250).await;

                // switch on LDOs
                ldo_en.set_high();
                Timer::after_millis(100).await;

                // switch on buck
                run_1v2.set_high();
                Timer::after_millis(250).await;

                // deassert reset
                reset.set_low();
                Timer::after_millis(250).await;
            }
            ResetManagerCommand::Shutdown => {
                info!("shutdown triggered!");
                // switch off all LDOs and assert reset
                run_1v2.set_low();
                ldo_en.set_low();
                reset.set_high();
            }
        }
    }
}

#[embassy_executor::task]
async fn pwm_manager(mut pwm1: SimplePwm<'static, TIM2>) {
    loop {
        let pwm = PWM_CTRL_CHANNEL.receive().await;
        let max_duty = pwm1.get_max_duty() as u32;
        for i in 0..2 {
            let (channel, value) = match i {
                0 => (PWMChannel::Ch1, pwm.pwm1_value),
                1 => (PWMChannel::Ch2, pwm.pwm2_value),
                _ => (PWMChannel::Ch3, 0),
            };
            let duty = max_duty * value as u32 / 100;
            info!("pwm{}: {}, max: {}", i, duty, max_duty);
            pwm1.set_duty(
                channel,
                if duty <= max_duty {
                    duty
                } else {
                    max_duty
                },
            );
        }

        Timer::after_millis(500).await;
    }
}
struct Disconnected {}

impl From<EndpointError> for Disconnected {
    fn from(val: EndpointError) -> Self {
        match val {
            EndpointError::BufferOverflow => panic!("Buffer overflow"),
            EndpointError::Disabled => Disconnected {},
        }
    }
}

enum Errors {
    None = 0,
    InvalidCommand = 1,
    ErrorDeserializingRequest = 2,
    ErrorSerializingResponse = 3,
    ErrorDeserializingRequestData = 4,
    ErrorSerializingResponseData = 5,
}

impl Errors {
    fn to_string(error: &Errors) -> &'static str {
        match error {
            Errors::InvalidCommand => "invalid command",
            Errors::ErrorDeserializingRequest => "error deserializing request",
            Errors::ErrorSerializingResponse => "error serializing response",
            Errors::ErrorDeserializingRequestData => "error deserializing request data",
            Errors::ErrorSerializingResponseData => "error serializing response data",
            _ => "unknown error",
        }
    }
}
enum Commands {
    Nop = 0,
    Control = 1,
    Status = 2,
    Reset = 3,
    Shutdown = 4,
}

impl Commands {
    fn from_i32(value: i32) -> Option<Commands> {
        match value {
            0 => Some(Commands::Nop),
            1 => Some(Commands::Control),
            2 => Some(Commands::Status),
            3 => Some(Commands::Reset),
            4 => Some(Commands::Shutdown),
            _ => None,
        }
    }
}

impl QResponse<'_> {
    fn default() -> QResponse<'static> {
        QResponse {
            id: 0,
            error: 0,
            data: Cow::Borrowed(&[0u8]),
        }
    }
}

// The response_bytes should be a mutable slice of u8, not a slice of a mutable slice.
async fn process_request<'a>(
    request: &QRequest<'_>,
    response: &mut QResponse<'_>,
) -> Result<usize, Errors> {
    let mut response_data = [0u8; 32];
    let mut response_len = 0;
    let error = Errors::None as i32;

    let op = Commands::from_i32(request.op);
    if op.is_none() {
        return Err(Errors::InvalidCommand);
    }

    match op.unwrap() {
        Commands::Nop => {
            // nop
        }
        Commands::Control => {
            let cmd: QControl = quick_protobuf::deserialize_from_slice(&request.data)
                .map_err(|_| Errors::ErrorDeserializingRequestData)?;

            info!(
                "received ctrl command with parameters state_1v2: {}, pwm1: {}, pwm2: {}",
                cmd.state_1v2, cmd.pwm1, cmd.pwm2
            );

            PWM_CTRL_CHANNEL
                .send(PWMControl {
                    pwm1_value: cmd.pwm1 as u16,
                    pwm2_value: cmd.pwm2 as u16,
                })
                .await;
        }
        Commands::Status => {
            info!("status");
            // get current power state
            let pgood_state = PGOOD.lock().await;

            let temp1 = TEMP1.lock().await;
            let temp1_data = *temp1;

            let temp2 = TEMP2.lock().await;
            let temp2_data = *temp2;

            let state = QState {
                pgood_1v2: *pgood_state as i32,
                temp1: temp1_data as i32,
                temp2: temp2_data as i32,
            };
            drop(pgood_state);
            drop(temp1);
            drop(temp2);

            response_len = state.get_size() + 1 /* varint */;
            debug!("response-len: {}", response_len);
            quick_protobuf::serialize_into_slice(&state, &mut response_data[..])
                .map_err(|_| Errors::ErrorSerializingResponseData)?;
        }
        Commands::Reset => RESET_MANAGER_SIGNAL.signal(ResetManagerCommand::Reset),
        Commands::Shutdown => RESET_MANAGER_SIGNAL.signal(ResetManagerCommand::Shutdown),
    };

    response.id = request.id;
    response.error = error;
    response.data = Cow::Owned(response_data[..response_len].to_vec());
    debug!(
        "response.id: {}, response.error:{}, response.data: {:?}",
        response.id,
        response.error,
        response_data[..response_len]
    );
    Ok(response_len)
}

async fn json_rpc<'d, T: Instance + 'd>(
    class: &mut CdcAcmClass<'d, Driver<'d, T>>,
) -> Result<(), Disconnected> {
    let mut request_bytes = [0u8; 64];
    let mut response_bytes = [0u8; 64];

    loop {
        let n = class.read_packet(&mut request_bytes).await?;

        let mut response = QResponse::default();

        let request = match quick_protobuf::deserialize_from_slice(&request_bytes[..n]) {
            Ok(req) => Some(req),
            Err(_) => {
                error!("{}", Errors::to_string(&Errors::ErrorDeserializingRequest));
                response = QResponse::default();
                response.error = Errors::ErrorDeserializingRequest as i32;
                None
            }
        };

        // if request is some then we can process the request
        if request.is_some() {
            if let Err(e) = process_request(&request.unwrap(), &mut response).await {
                error!("{}", Errors::to_string(&e));
                response = QResponse::default();
                response.error = e as i32;
            }
        }

        let serialized_len = response.get_size() + 1 /* varint */;
        if quick_protobuf::serialize_into_slice(&response, &mut response_bytes).is_err() {
            error!("{}", Errors::to_string(&Errors::ErrorSerializingResponse));
            continue;
        }

        class
            .write_packet(&response_bytes[..serialized_len])
            .await?;
    }
}

#[embassy_executor::task]
async fn temp_manager(mut i2c: I2c<'static, I2C2, DMA1_CH4, DMA1_CH5>) {
    loop {
        Timer::after_millis(5000).await;

        for i in 0..2 {
            let mut data = [0u8; 2];
            if let Err(e) = i2c.read(0x48 + i, &mut data).await {
                error!("i2c error: {:?}", e);
                continue;
            }

            let mut temp_data = ((data[0] as u16) << 4) | ((data[1] as u16) >> 4);

            if temp_data > 2047 {
                temp_data -= 4096
            }

            info!("read temp{}: {}", i + 1, temp_data);

            if i == 0 {
                let mut temp1 = TEMP1.lock().await;
                *temp1 = temp_data;
            } else {
                let mut temp2 = TEMP2.lock().await;
                *temp2 = temp_data;
            }
        }

    }
}

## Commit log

2024-01-15 initial commit (rev2)
    [FP1006V2-R.STEP, barrel-jack.step, bm1366.kicad_sch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]
2024-01-15 updated bom and gerbers
    [bm1366.kicad_sch, digikey.csv, pi.kicad_sch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]
2024-01-15 fixed bom
    [digikey.csv]
2024-01-16 updated BOM and replaces bss138 and 3.3V LDO with parts that are available
    [bm1366.kicad_sch, digikey.csv, power.kicad_sch]
2024-01-17 switched to buffered uart
2024-01-24 replaced 20k with 22k on feedback voltage divider to increase core voltage by 0.05V. 485MHz working properly now at 100% cooling
    [digikey.csv, power.kicad_sch]
2024-01-26 fixed broken bom
    [digikey.csv]
2024-01-27 made pwm2 work, cargo clippy & fmt
2024-01-27 switched dma uart to buffereduart
2024-01-29 updated ibom
    [qaxe.kicad_pcb]
2024-01-30 4.7u cap was missing in digikey bom
    [digikey.csv, power.kicad_sch]
2024-02-02 added run.sh scripts for fw rev1 and rev2
    [power.kicad_sch]
2024-02-14 fixed wrong lm1117 variant in bom
    [digikey.csv, power.kicad_sch, qaxe.kicad_pcb]
2024-02-21 rev2 fw fix, added resyncing to preamble
    [qaxe.rs]
2024-02-22 bigger stm32 variant that has usb bootloader
    [pi.kicad_sch, power.kicad_sch]
2024-02-22 fw-rev3 (with stm32l151cc - only change)
2024-02-22 updated bom and ibom for stm32l151cc
    [digikey.csv]
2024-02-22 updated board with -CC variant
    [qaxe.kicad_pcb]
2024-02-27 3d design files (back missing, comes later)
    [grill-part1.stl, grill-part2.stl]
2024-02-27 added case
    [case.stl]
2024-03-04 back of case added
    [back.stl]
2024-03-12 added points for pin 1 on Us
    [qaxe-B_Cu.gbl, qaxe-B_Mask.gbs, qaxe-B_Paste.gbp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]
2024-04-01 1368 support
    [bm1366.kicad_sch, pi.kicad_sch, power.kicad_sch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]
2024-04-01 gerbers for 1368
    [bm1366.kicad_sch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]
2024-04-01 updated stm32 to L072 on normal qaxe
    [bm1366.kicad_sch, digikey.csv, pi.kicad_sch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]
2024-04-01 updated qaxe+ to L072
    [digikey.csv, pi.kicad_sch, qaxe.kicad_pcb]
2024-05-03 updated L151 with L072 for qaxe+
    [digikey.csv, pi.kicad_sch, qaxe.kicad_pcb]
2024-05-03 some bom fixes
    [digikey.csv, pi.kicad_sch, power.kicad_sch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]
2024-05-15 rev4.1 qaxe+ (added pull downs on NRSTI)
    [bm1366.kicad_sch, digikey.csv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]
2024-05-15 improvements on power managemend and reset for qaxe+
    [qaxe.rs]
2024-08-12 initial nerdqaxe+
    [FP1006V2-R.STEP, KMR231GLFS.stp, Littelfuse 0154.500DRT without value_black v2.step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]
2024-08-12 nerdqax+ digikey bom
    [digikey.csv]
2024-08-18 removed big M4 connectors because they were only for the prototypes
    [nerdqaxe+-B_Cu.gbl, nerdqaxe+-B_Mask.gbs, nerdqaxe+-B_Paste.gbp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]
2024-09-27 removed ph2-dis solderjumper because it's not needed
    [nerdqaxe+-B_Cu.gbl, nerdqaxe+-B_Mask.gbs, nerdqaxe+-B_Paste.gbp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]
2024-10-18 initial ++ commit
    [DCJ250-20-B-XX-X_REVA1.step, FP1006V2-R.STEP, KMR231GLFS.stp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]
2024-10-18 ibom and digikey order list
    [digikey.csv]
2024-10-18 updated fuse to 8A
    [digikey.csv, nerdqaxe++.kicad_sch]
2024-10-18 added holes for another cooler
    [nerdqaxe++-B_Cu.gbl, nerdqaxe++-B_Mask.gbs, nerdqaxe++-B_Paste.gbp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]
2024-12-08 added measurements
    [nerdqaxe+.kicad_pcb]
2025-01-02 digikey bom with refs
    [digikey_with_refs.csv]
2025-02-17 fixed temp sensing connection to the buck on the ++
    [nerdqaxe++-B_Cu.gbl, nerdqaxe++-B_Mask.gbs, nerdqaxe++-B_Paste.gbp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]
2025-04-09 updated 220uF on ++ to 25V
    [bm1366.kicad_sch, digikey.csv, digikey_with_refs.csv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]
2025-04-09 updated bom of + for 24V cap
    [bm1366.kicad_sch, digikey.csv, digikey_with_refs.csv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]
2025-04-09 fixed wrong value
    [power.kicad_sch]
2025-04-26 disabled weird lga115x heatsinks in 3d view
2026-01-11 moved old qaxes to legaxy
    [FP1006V2-R.STEP, KMR231GLFS.stp, Littelfuse 0154.500DRT without value_black v2.step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]
2026-01-15 disabled FCCM
    [nerdqaxe++-B_Cu.gbl, nerdqaxe++-B_Mask.gbs, nerdqaxe++-B_Paste.gbp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]
